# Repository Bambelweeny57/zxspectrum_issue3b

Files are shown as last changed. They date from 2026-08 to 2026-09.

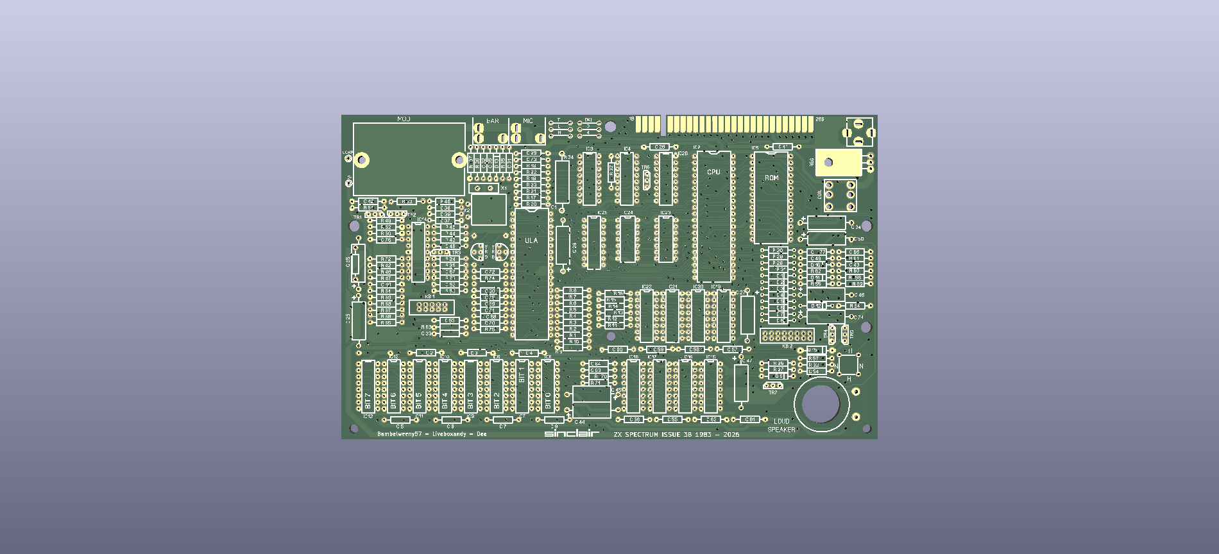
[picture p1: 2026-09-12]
images/unpopulated - issue3b.png

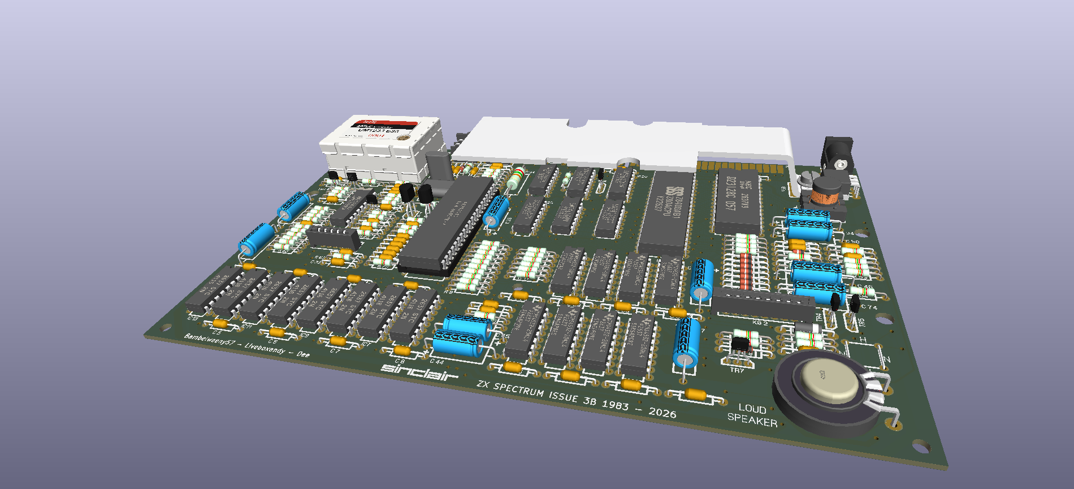
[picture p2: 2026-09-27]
images/issue3b.png

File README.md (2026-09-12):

# **ZX Spectrum Issue 3B — KiCad Reconstruction**

A faithful KiCad recreation of the **Sinclair ZX Spectrum Issue 3B motherboard**, reconstructed from original Gerber data and fully validated through multiple successful builds.  
This project preserves the 3B layout in an editable, open format and includes several companion PCBs designed to modernise, repair, or enhance the original Spectrum hardware.

---

## 🧭 Project Purpose

The aim of this repository is to provide a clean, accurate, and reproducible version of the Issue 3B board for:

- Restoring original machines  
- Building new units from scratch  
- Hardware experimentation and modding  
- Long‑term preservation of Sinclair’s design  

All PCBs included here have been **physically manufactured and tested**.

---

## 🛠️ Included PCBs

### **✔️ Issue 3B Motherboard (KiCad Reconstruction)**  
A complete KiCad recreation of the original Issue 3B board.

- Rebuilt directly from Gerbers  
- Trace‑accurate routing  
- Multiple boards assembled and working perfectly  
- Compatible with original components and modern equivalents  

---

### **✔️ Coil Replacement PCB**  
A compact, reliable drop‑in replacement for the original Spectrum coil assembly.

- Tested and working  
- More consistent output than ageing originals  
- Builder‑friendly footprint and assembly  

---

### **✔️ Composite Mod PCB (Internal Modulator Replacement)**  
This PCB is designed to **fit inside the original RF modulator can**, replacing the internal circuitry while keeping the metal can for authenticity.

- Produces a clean composite video output  
- Eliminates RF noise and modulator‑related issues  
- Fully validated on real hardware  
- Ideal for restorations where the external appearance should remain original  

---

### **✔️ Composite Modulator Replacement PCB**  
A full PCB replacement for the RF modulator can itself.

- Suitable for new builds or heavily damaged modulators  
- Provides modern composite output in a clean, serviceable form  
- Tested and working  

---

## 🧩 Issue 3B Schematic

A full schematic for the **Issue 3B motherboard** is now complete.  
It lives in the main **`/src`** directory alongside the KiCad PCB project and is useful for reference, verification, and troubleshooting.

- Based on the reconstructed PCB  
- Continuously refined as traces and nets are validated  
- Intended to become a complete, accurate representation of the 3B circuitry  
- A PDF export is also included in **`/documents`** for quick viewing

---

## 📁 Repository Structure

| Path | Description |
|---|---|
| `/bom` | Interactive Bill of Materials |
| `/case` | £D models and images of a alternatice case |
| `/documents` | Schematics etc. |
| `/gerber` | Fabrication files |
| `/images` | Images of the PCB's |
| `/keyboard` | Mechanical Keyswitch Keyboard to fit the Case |
| `/src` | KiCad project files for the Issue 3B board |
| `/zx_coil` | Coil replacement PCB |
| `/zx_composite_mod` | Composite mod PCB (internal modulator replacement) |
| `/zx_composite_modulator` | Full modulator replacement PCB |
| `README.md` | Project overview |

---

## 🔧 Build Status

All PCBs in this repository have been **successfully manufactured, assembled, and tested**.

| PCB | Status |
|-----|---|
| Issue 3B Motherboard | ✅ Working |
| Coil Replacement PCB | ✅ Working |
| Composite Mod PCB | ✅ Working |
| Composite Modulator PCB | ✅ Working |

---

## 📐 About the Issue 3B Revision

The Issue 3B is one of the later 48K Spectrum board revisions, featuring:

- Improved manufacturing consistency  
- Minor routing and grounding refinements  
- Updated power regulation layout  
- Compatibility with both early and late ULAs  

This reconstruction preserves the original routing and component placement as closely as possible.

---

## 🤝 Contributing

Contributions that improve accuracy, documentation, or long‑term preservation of the Issue 3B are welcome.  
This includes:

- Verified corrections to the schematic or PCB reconstruction  
- High‑resolution board scans, trace photos, or component placement references  
- Improvements to KiCad symbols, footprints, or net annotations  
- Build reports, troubleshooting notes, or compatibility findings  
- Additional companion PCBs that relate to the 3B ecosystem  

Please open an issue or pull request with clear details so changes can be reviewed and validated against real hardware where possible.

---

## 🤝 Credits

Based on the redraw by PABB - https://www.pcbway.com/project/shareproject/ZX_Spectrum_48_Issue_3B_Redrawn.html

Special thanks to Liveboxandy for reconstructing the base footprints for the iBOM and 3D Models view and Dee for the Coil, Keyboard and Audio Connectors, Modulator, Speaker, ULA, CPU, ROM and Heat Sink 3D Models.

---

## 📜 License

This project is released for educational, preservation, and hobbyist use.  
You are free to study, modify, and build from the files provided.

The original Sinclair ZX Spectrum design remains the intellectual property of its respective rights holders.  
Please respect the historical significance of the original hardware.

---

## 🚀 How to Use This Project

### **Open in KiCad**
```bash
git clone https://github.com/Bambelweeny57/zxspectrum_issue3b

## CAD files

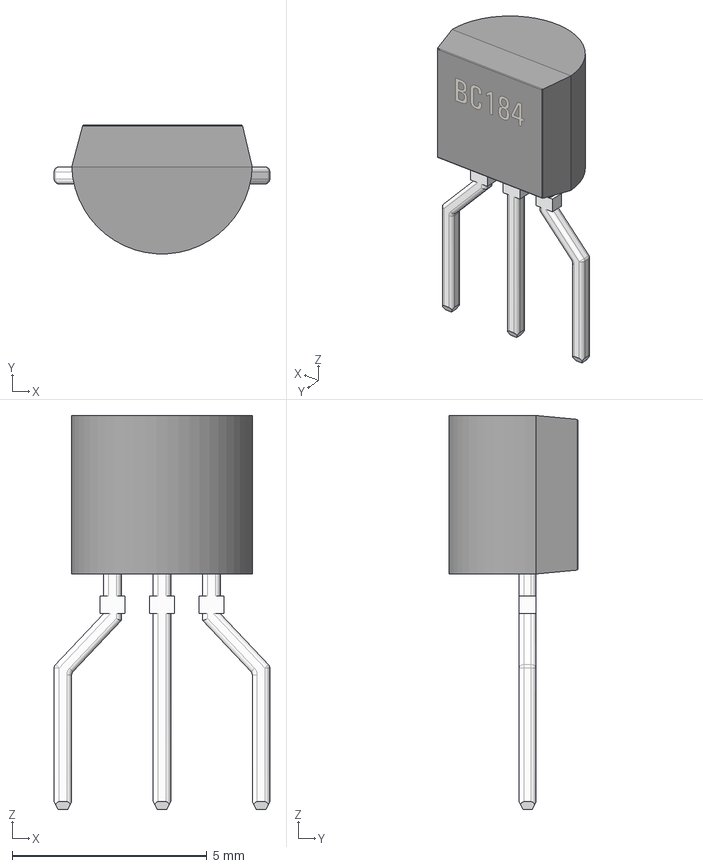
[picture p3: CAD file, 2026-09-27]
src/STPS/BC184.step
5.53 x 3.30 x 10.1 mm
Legs
TO92

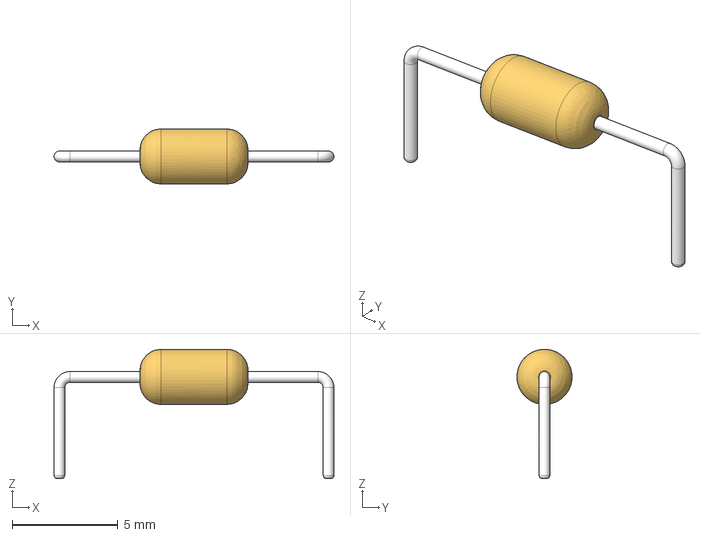
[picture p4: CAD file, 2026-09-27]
src/STPS/CAP_AXIAL_THT_L5.1-D3.1-P12.70.step
13.2 x 2.60 x 6.10 mm

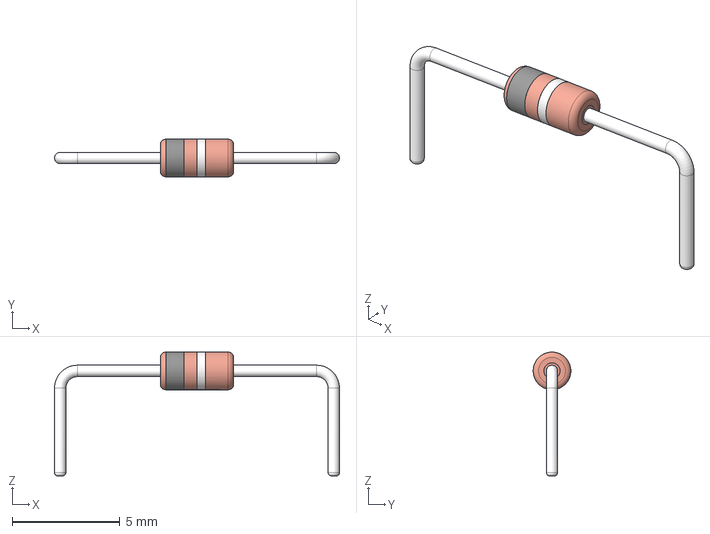
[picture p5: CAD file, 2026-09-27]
src/STPS/DO-35_P12.70-D0.53.step
13.2 x 1.75 x 5.75 mm

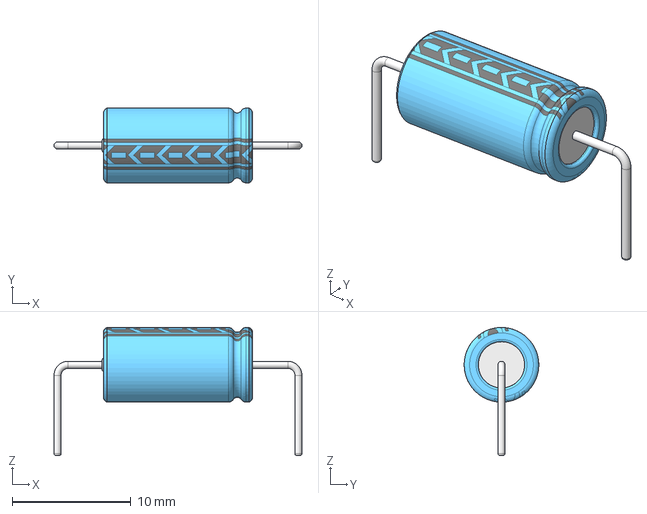
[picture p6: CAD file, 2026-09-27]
src/STPS/CAP-TH_BD6.3-L12.0-P20.32-D0.6.step
20.9 x 6.30 x 10.8 mm

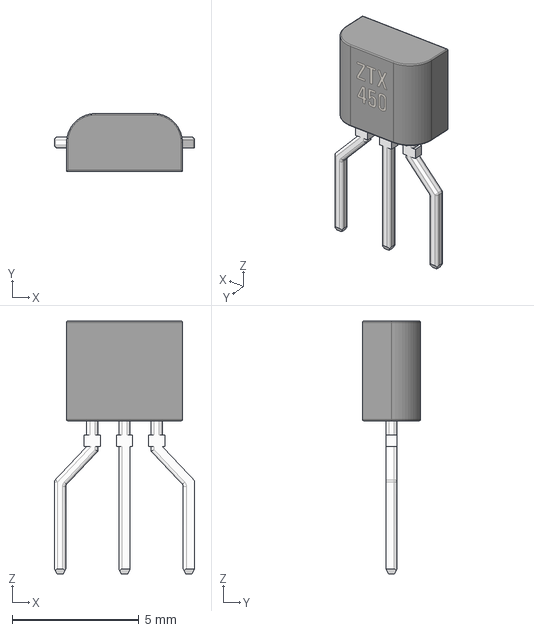
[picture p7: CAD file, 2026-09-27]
src/STPS/ZTX_450.step
5.53 x 2.29 x 9.98 mm
Legs
ELINE

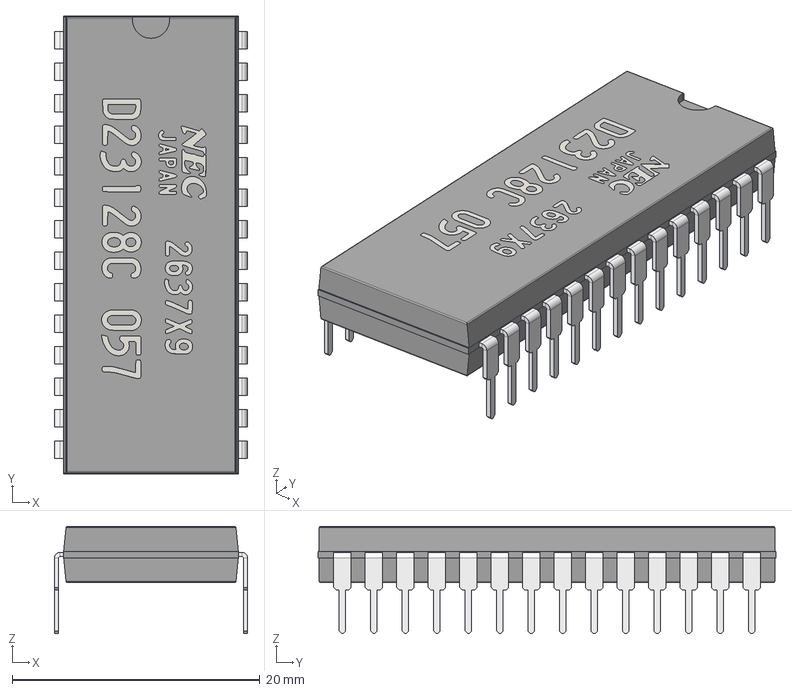
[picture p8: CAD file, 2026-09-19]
src/STPS/ROM NEC D2318C.step
15.6 x 37.0 x 8.64 mm
Basic - DIP40 Wide v2
DIP Pin v2
DIP Pin v2(Mirror)

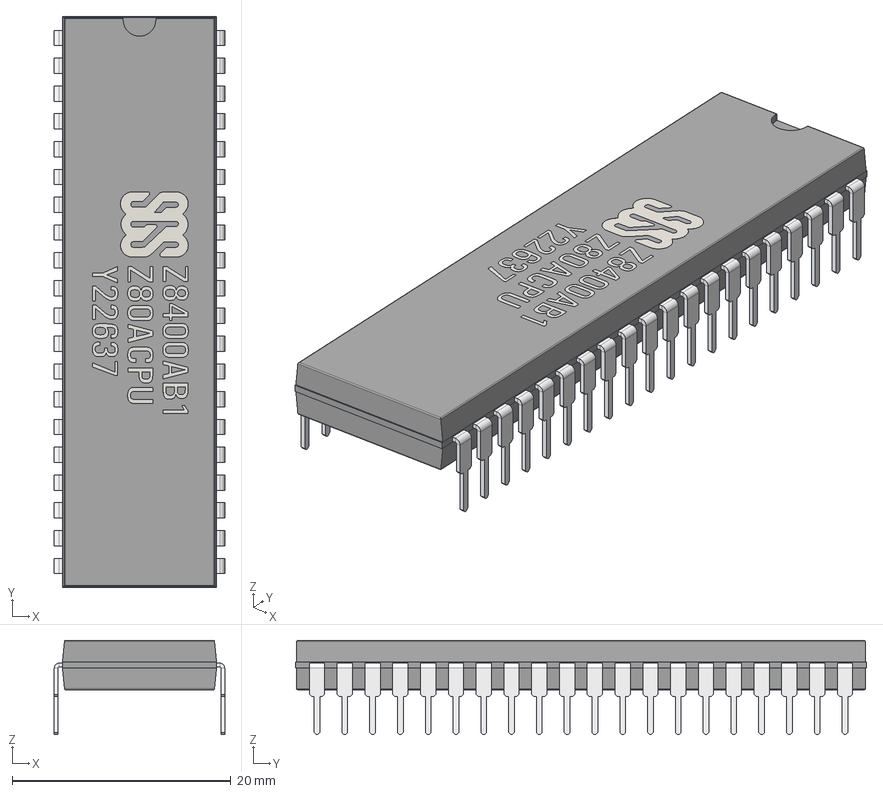
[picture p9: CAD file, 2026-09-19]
src/STPS/Z80 - SGS.step
15.6 x 52.2 x 8.64 mm
Basic - DIP40 Wide v2
DIP Pin v2
DIP Pin v2(Mirror)

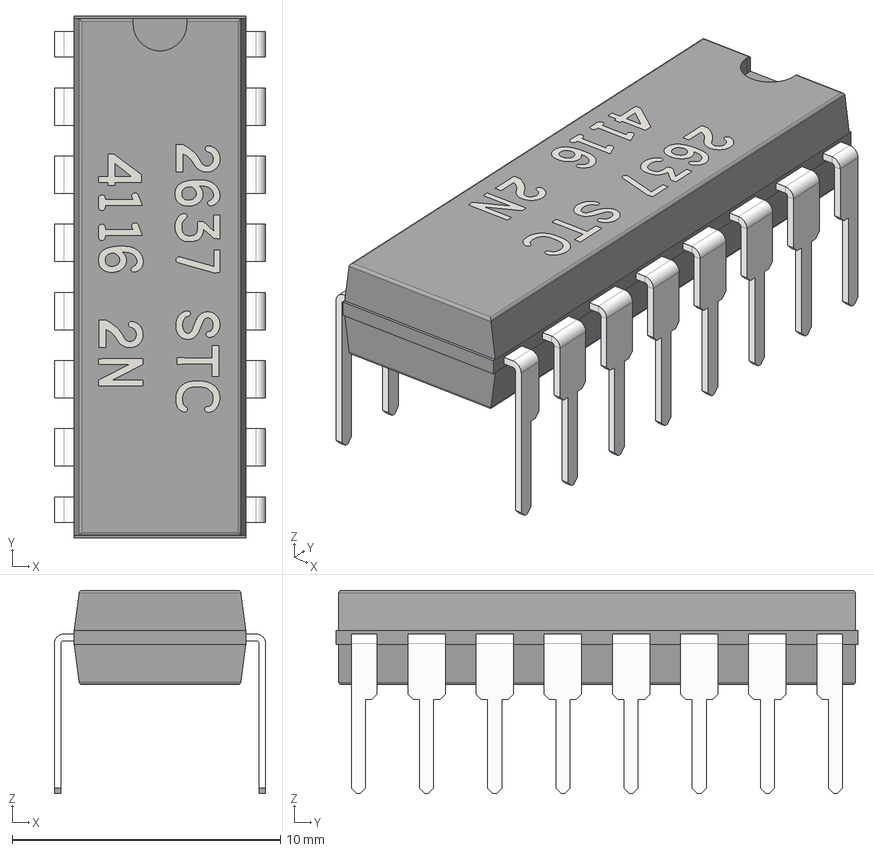
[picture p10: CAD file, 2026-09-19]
src/STPS/STC_4116.step
7.87 x 19.5 x 7.57 mm
Basic - DIP 7.62 v3
DIP Pin 14-20 v3
DIP Pin 14-20 v3(Mirror)

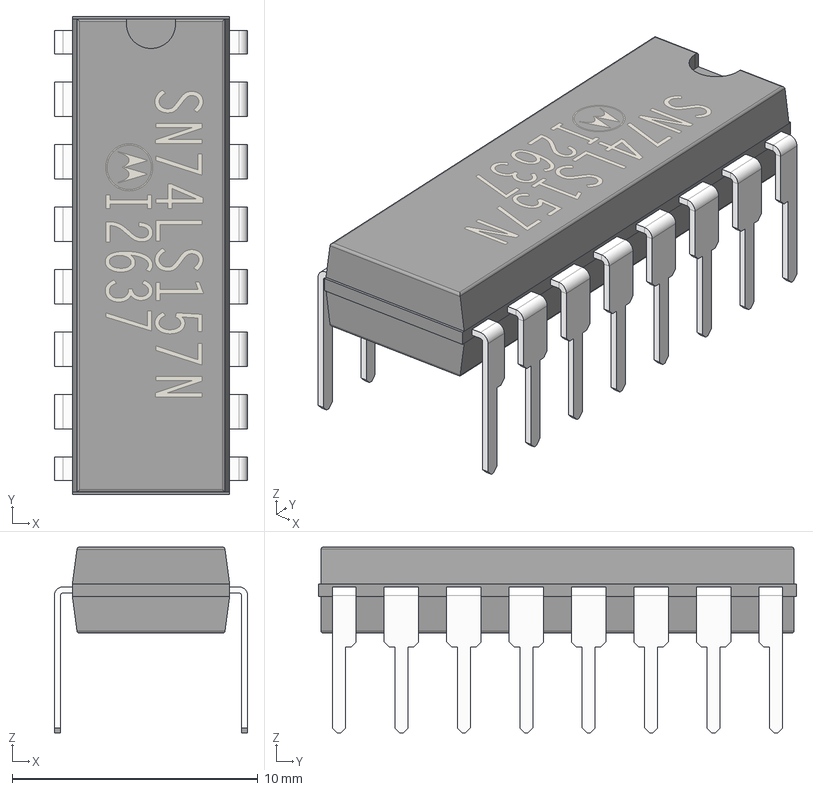
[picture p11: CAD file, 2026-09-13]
src/STPS/MOT_SN74LS157N.step
7.87 x 19.5 x 7.57 mm
Basic - DIP 7.62 v3
DIP Pin 14-20 v3
DIP Pin 14-20 v3(Mirror)

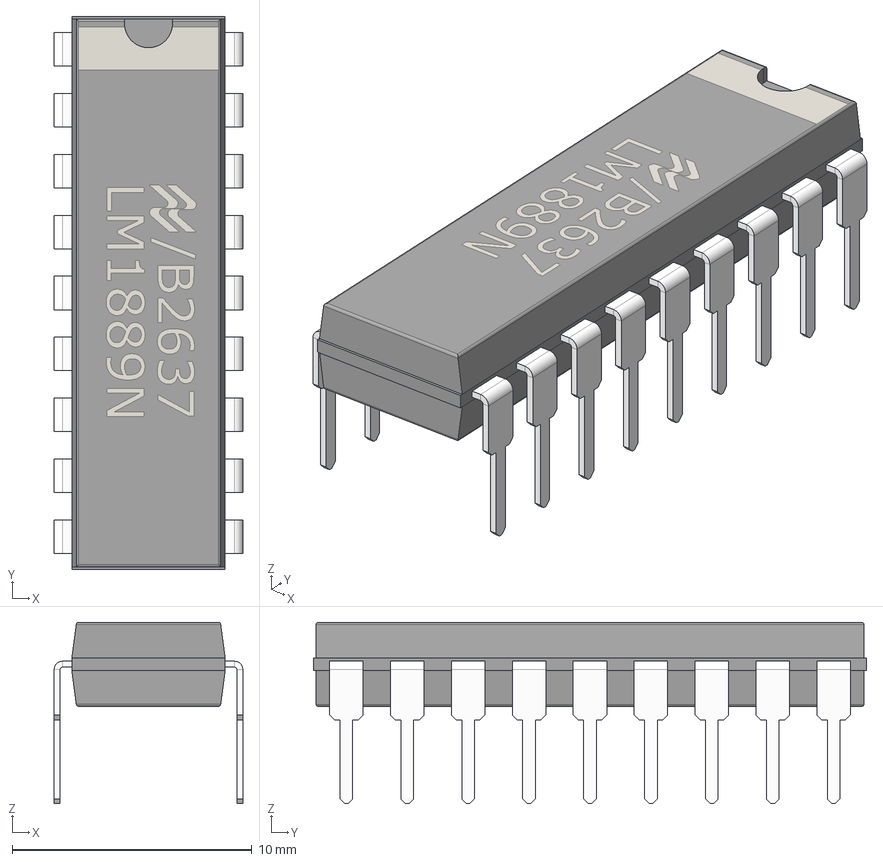
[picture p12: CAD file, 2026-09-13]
src/STPS/NS_LM1889N.step
7.87 x 23.1 x 7.57 mm
Basic - DIP 7.62 v3
DIP Pin 14-20 v3
DIP Pin 14-20 v3(Mirror)

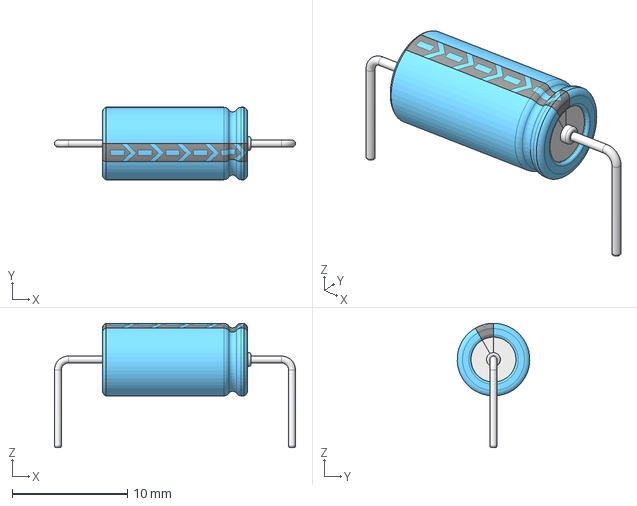
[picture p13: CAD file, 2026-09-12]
src/STPS/Axial Capacitor.step
20.9 x 6.29 x 10.8 mm

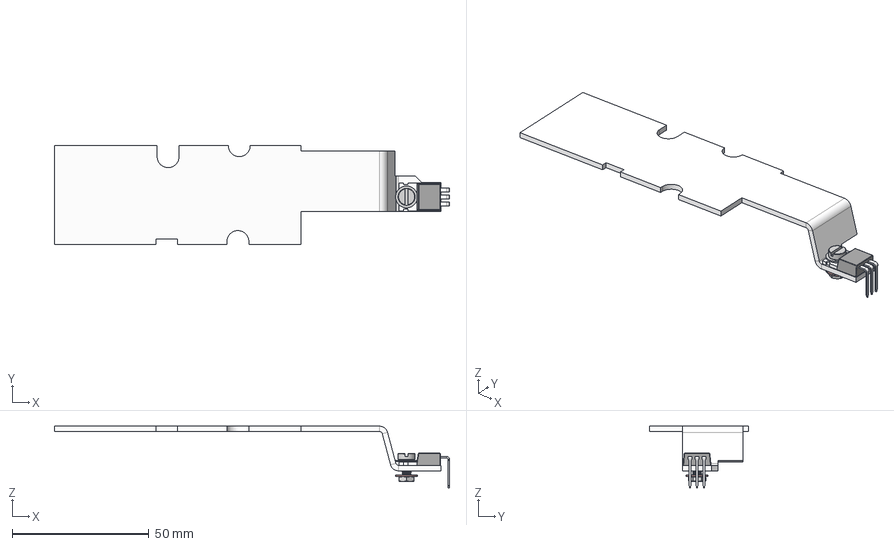
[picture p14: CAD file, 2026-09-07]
src/STPS/LM7805 with Heatsink i3.step
144.3 x 36.0 x 22.5 mm
Heatsink
TO-220-3
Screw
93925A250_Internal Tooth Lock Washers
90695A033_Medium-Strength Steel Thin-Profile Hex Nut
Fibre Washer

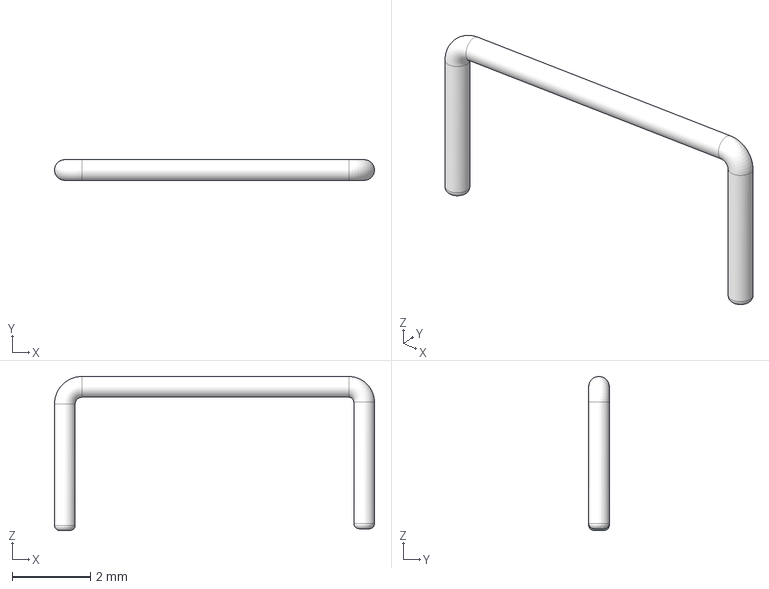
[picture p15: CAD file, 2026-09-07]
src/STPS/Jumper.step
8.18 x 0.53 x 3.94 mm

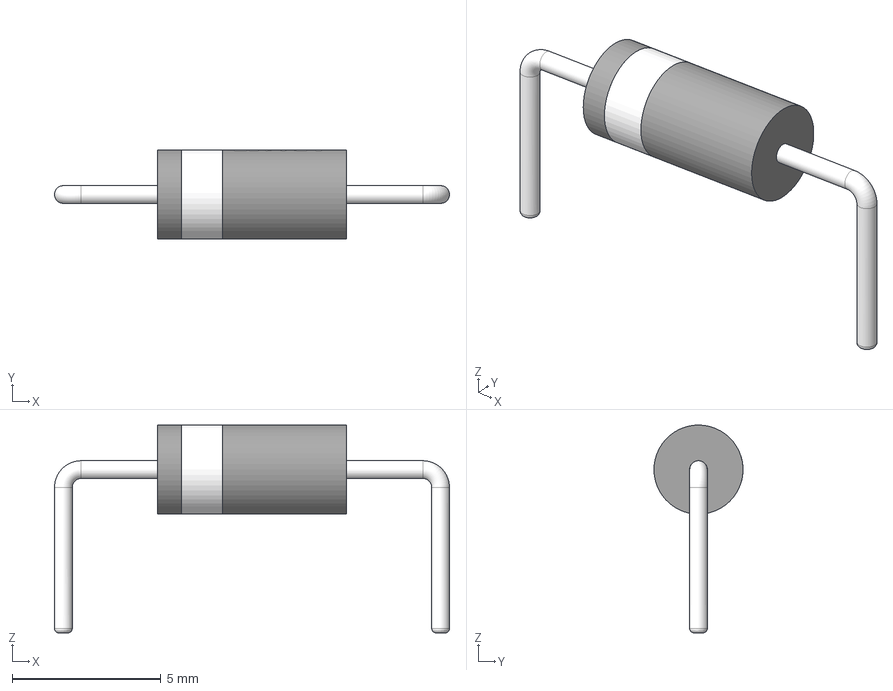
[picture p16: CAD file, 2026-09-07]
src/STPS/DO-35_P12.70_BA157.step
13.3 x 3.00 x 7.00 mm
Wire
Diode Body

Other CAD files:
src/STPS/MOT_SN74532N.step
src/STPS/MOT_SN74LS00N.step
src/STPS/ITT_4116.step
src/STPS/TI_TMS4532.step
src/STPS/13.34x13.34 Bobin.STEP
src/STPS/22-02-3053.stp
src/STPS/22-02-3083.stp
src/STPS/AUDIO_JACK_3PIN.step
src/STPS/COIL_L1.step
src/STPS/CONN-TH_5P-P2.54_520315-5.step
src/STPS/CONN-TH_8P-P2.54_520315-8.step
src/STPS/CP 13x5x0.5x20.32.STEP
src/STPS/Capacitor Ceramic No Polarity axial 12.70.STEP
src/STPS/Crystal-HC18-U RA.STEP
src/STPS/Crystal-Low.stp
src/STPS/DC Power Connector FC68148_20DC10A_202.1mm.STP
src/STPS/DIP-14_W7.62mm.step
src/STPS/DIP-14_W7.62mm_Socket.step
src/STPS/DIP-16_W7.62mm.step
src/STPS/DIP-16_W7.62mm_Socket.step
src/STPS/DIP-18_W7.62mm.step
src/STPS/DIP-18_W7.62mm_Socket.step
src/STPS/DIP-24_W10.16mm.step
src/STPS/DIP-24_W10.16mm_Socket.step
src/STPS/DIP-28_W15.24mm.step
src/STPS/DIP-28_W15.24mm_Socket.step
src/STPS/DIP-40_W15.24mm.step
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

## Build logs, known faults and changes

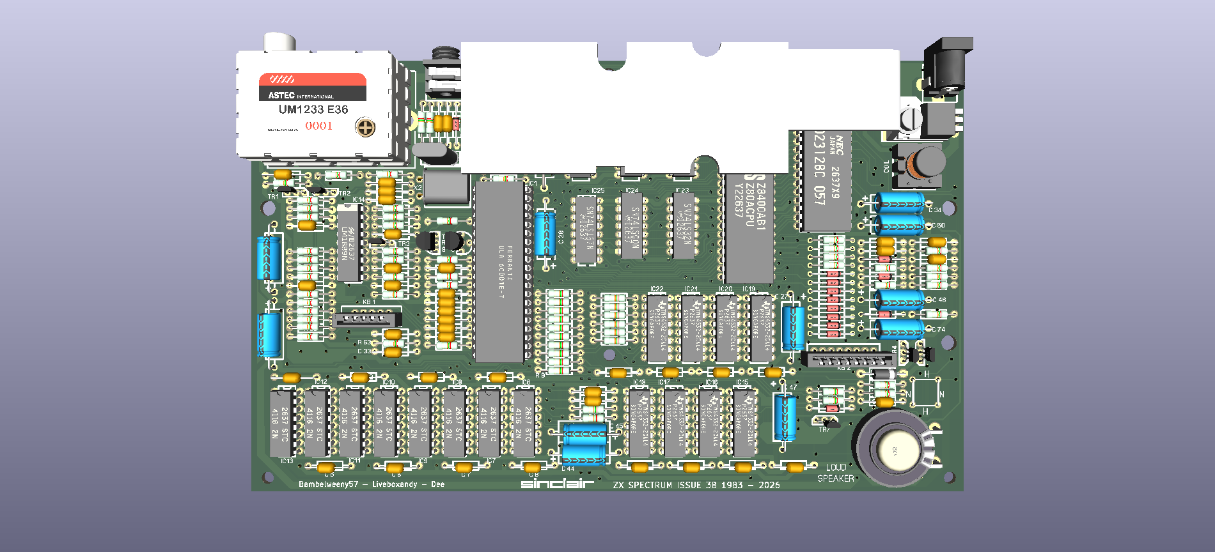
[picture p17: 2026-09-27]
images/populated - issue3b.png

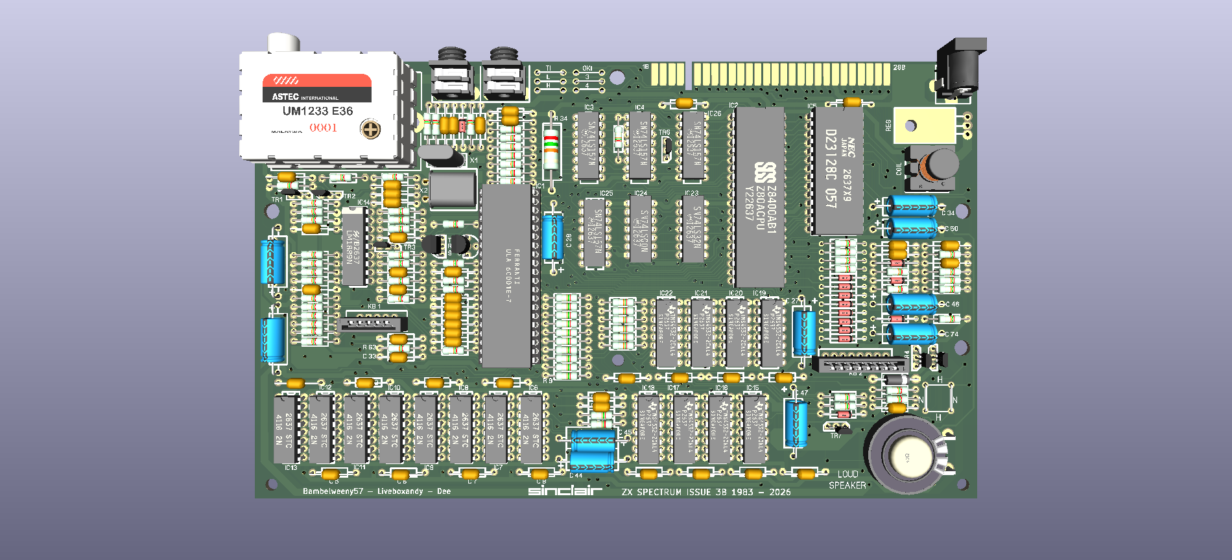
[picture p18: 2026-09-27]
images/populated - no heatsink - issue3b.png

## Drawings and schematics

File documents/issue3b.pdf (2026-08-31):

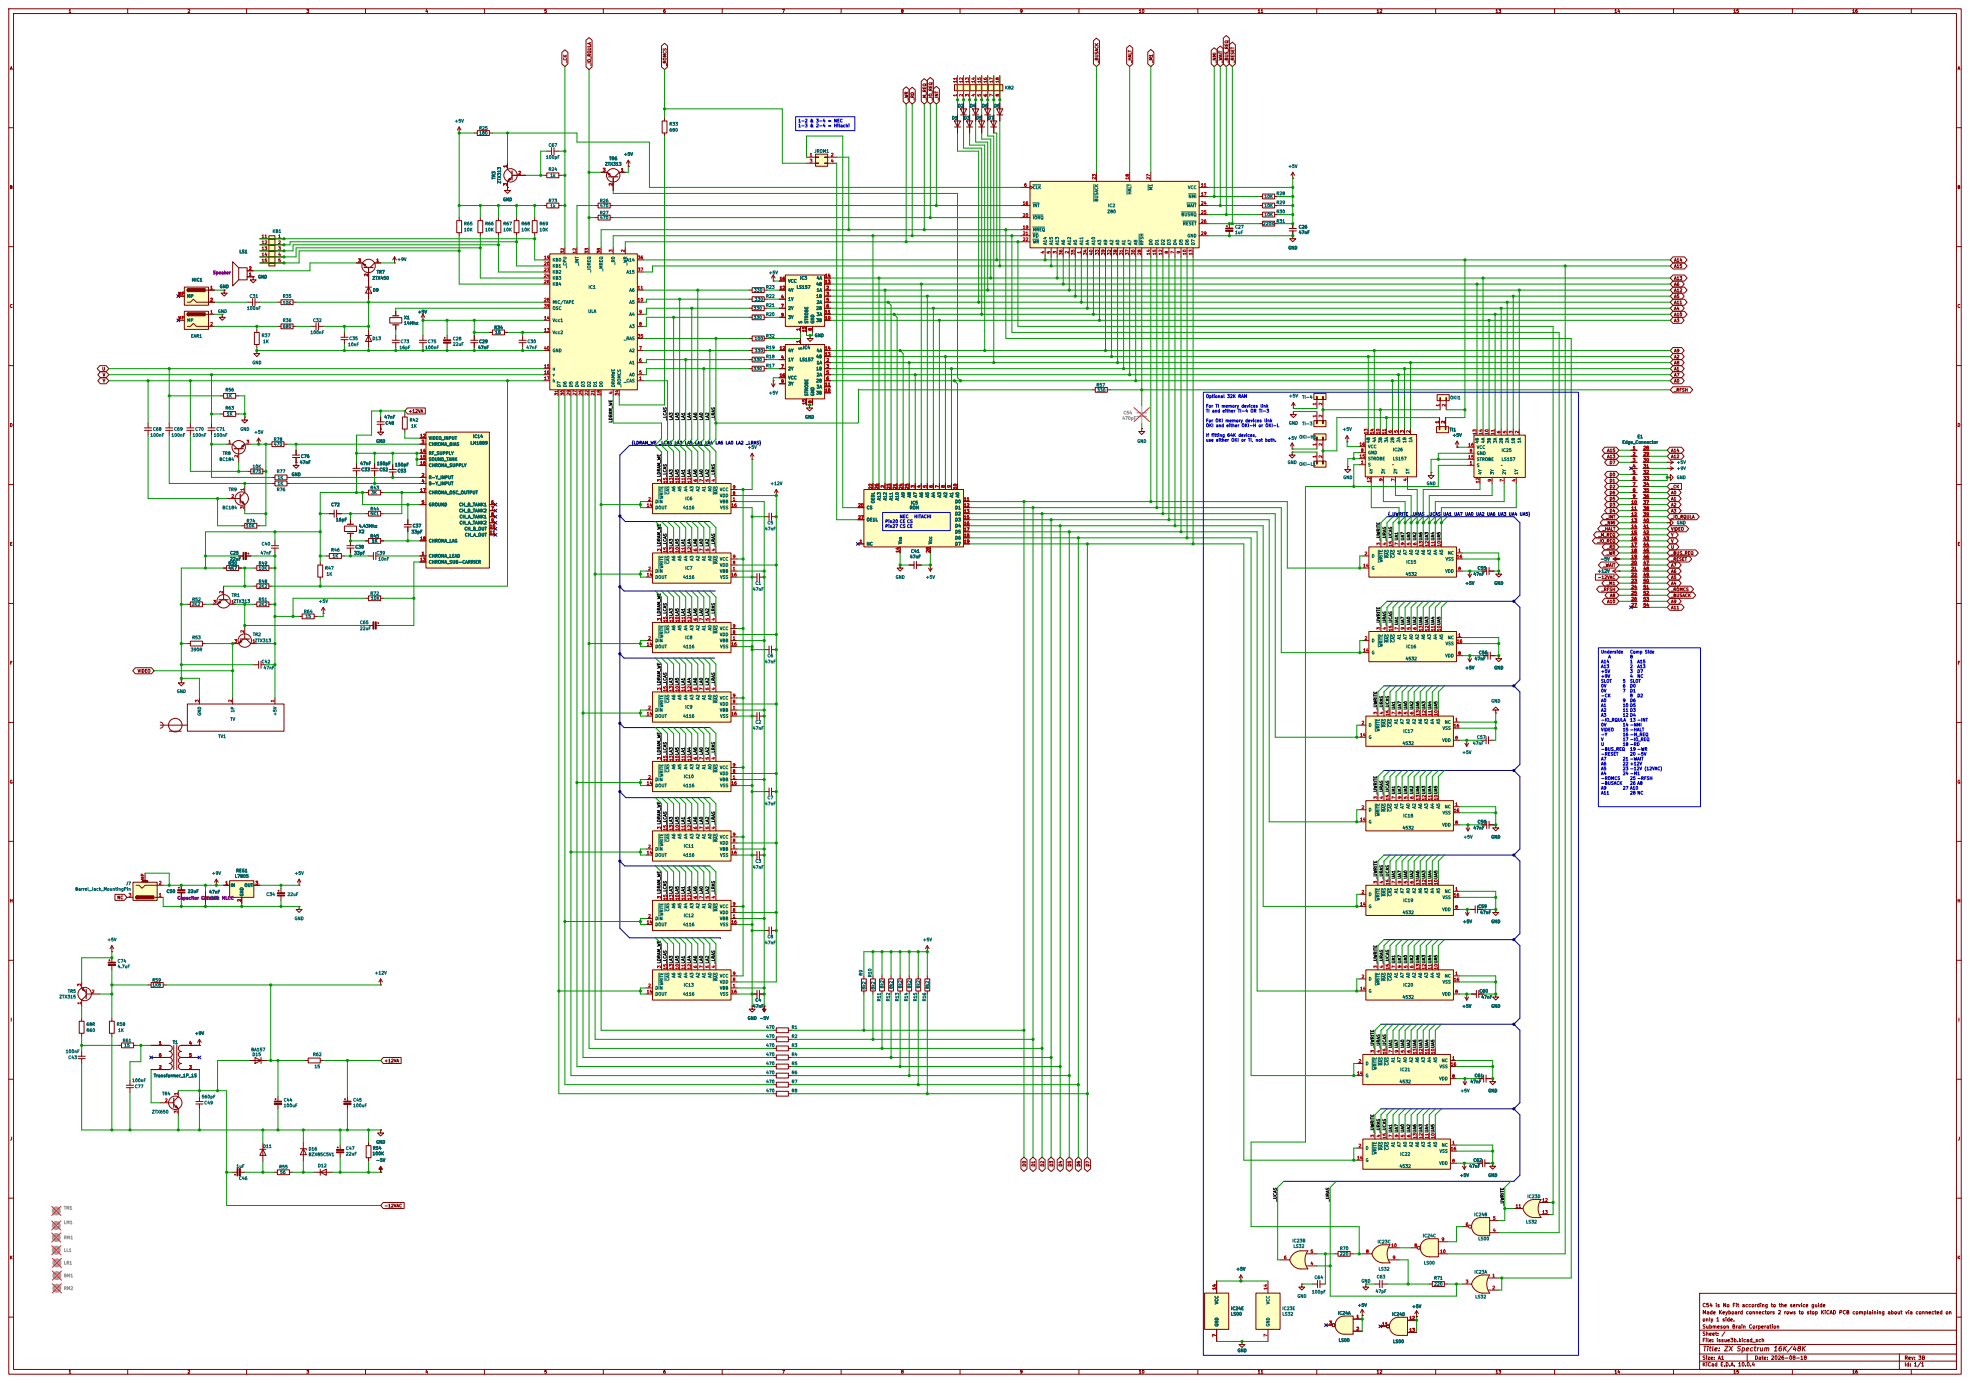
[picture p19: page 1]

For TI memory devices link
TI and either TI-4 OR TI-3

For OKI memory devices link OKI and either OKI-H or OKI-L

IC5 ROM
NEC HITACHI Pin20 CE CS Pin27 CS CE

VDD | 8 A7

VDD 4532 | 8 A7

Made Keyboard connectors 2 rows to stop KiCAD PCB complaining about via connected on C54 is No Fit according to the service guide

Size: A1 | Rev: 3B
KiCad E.D.A. 10.0.4 | Id: 1/1

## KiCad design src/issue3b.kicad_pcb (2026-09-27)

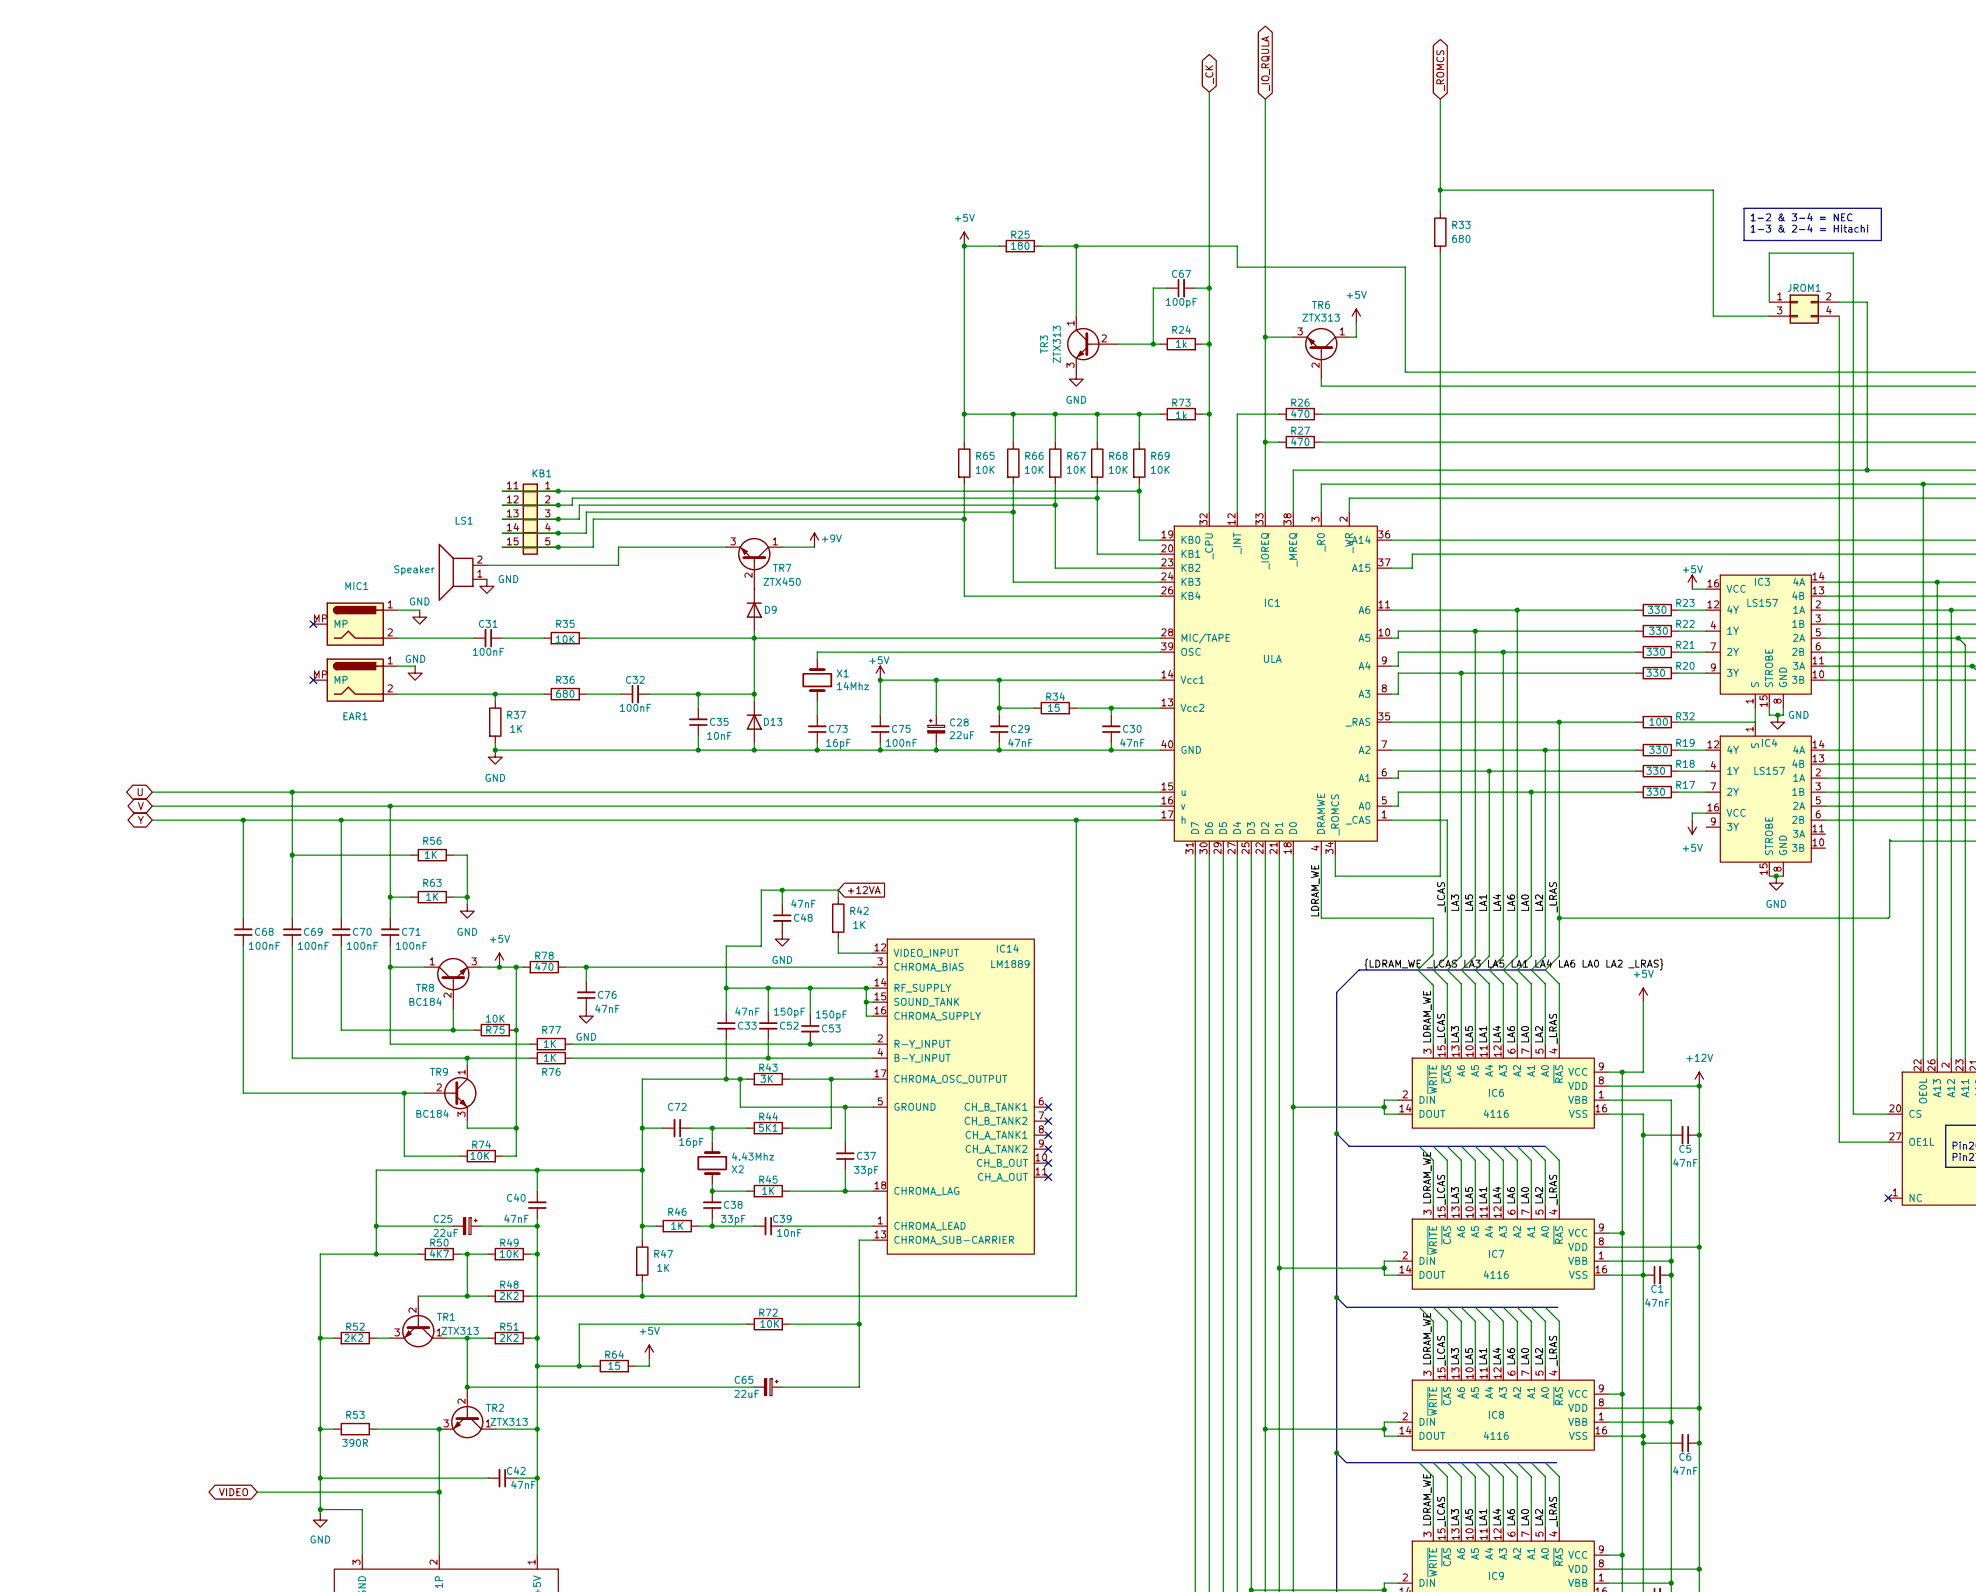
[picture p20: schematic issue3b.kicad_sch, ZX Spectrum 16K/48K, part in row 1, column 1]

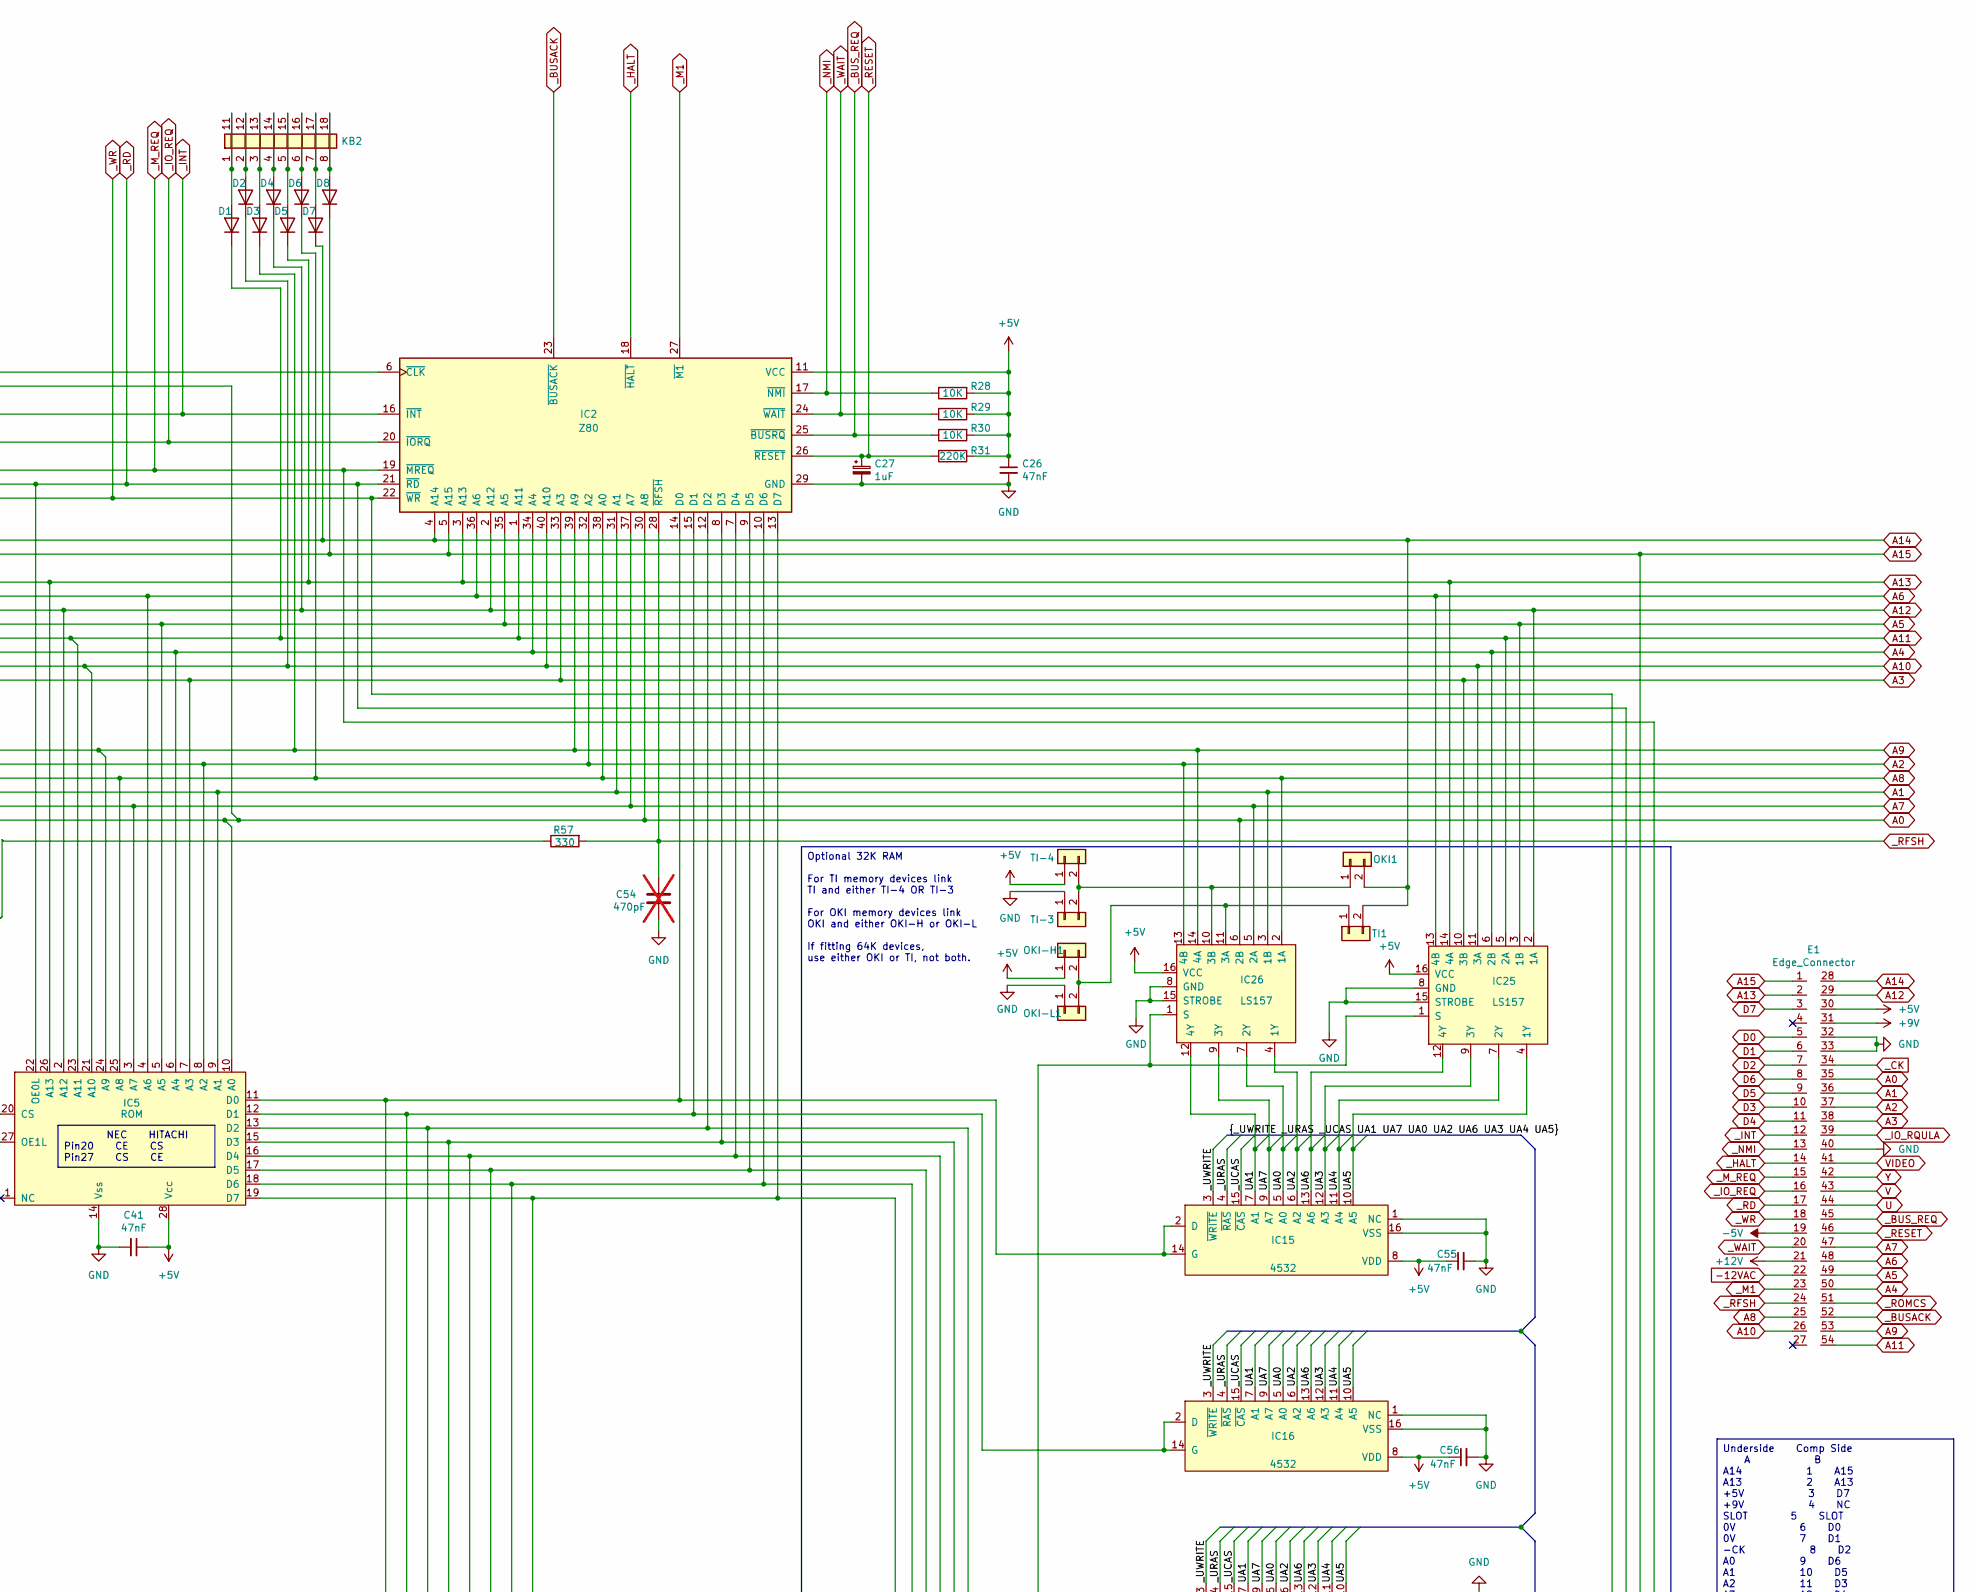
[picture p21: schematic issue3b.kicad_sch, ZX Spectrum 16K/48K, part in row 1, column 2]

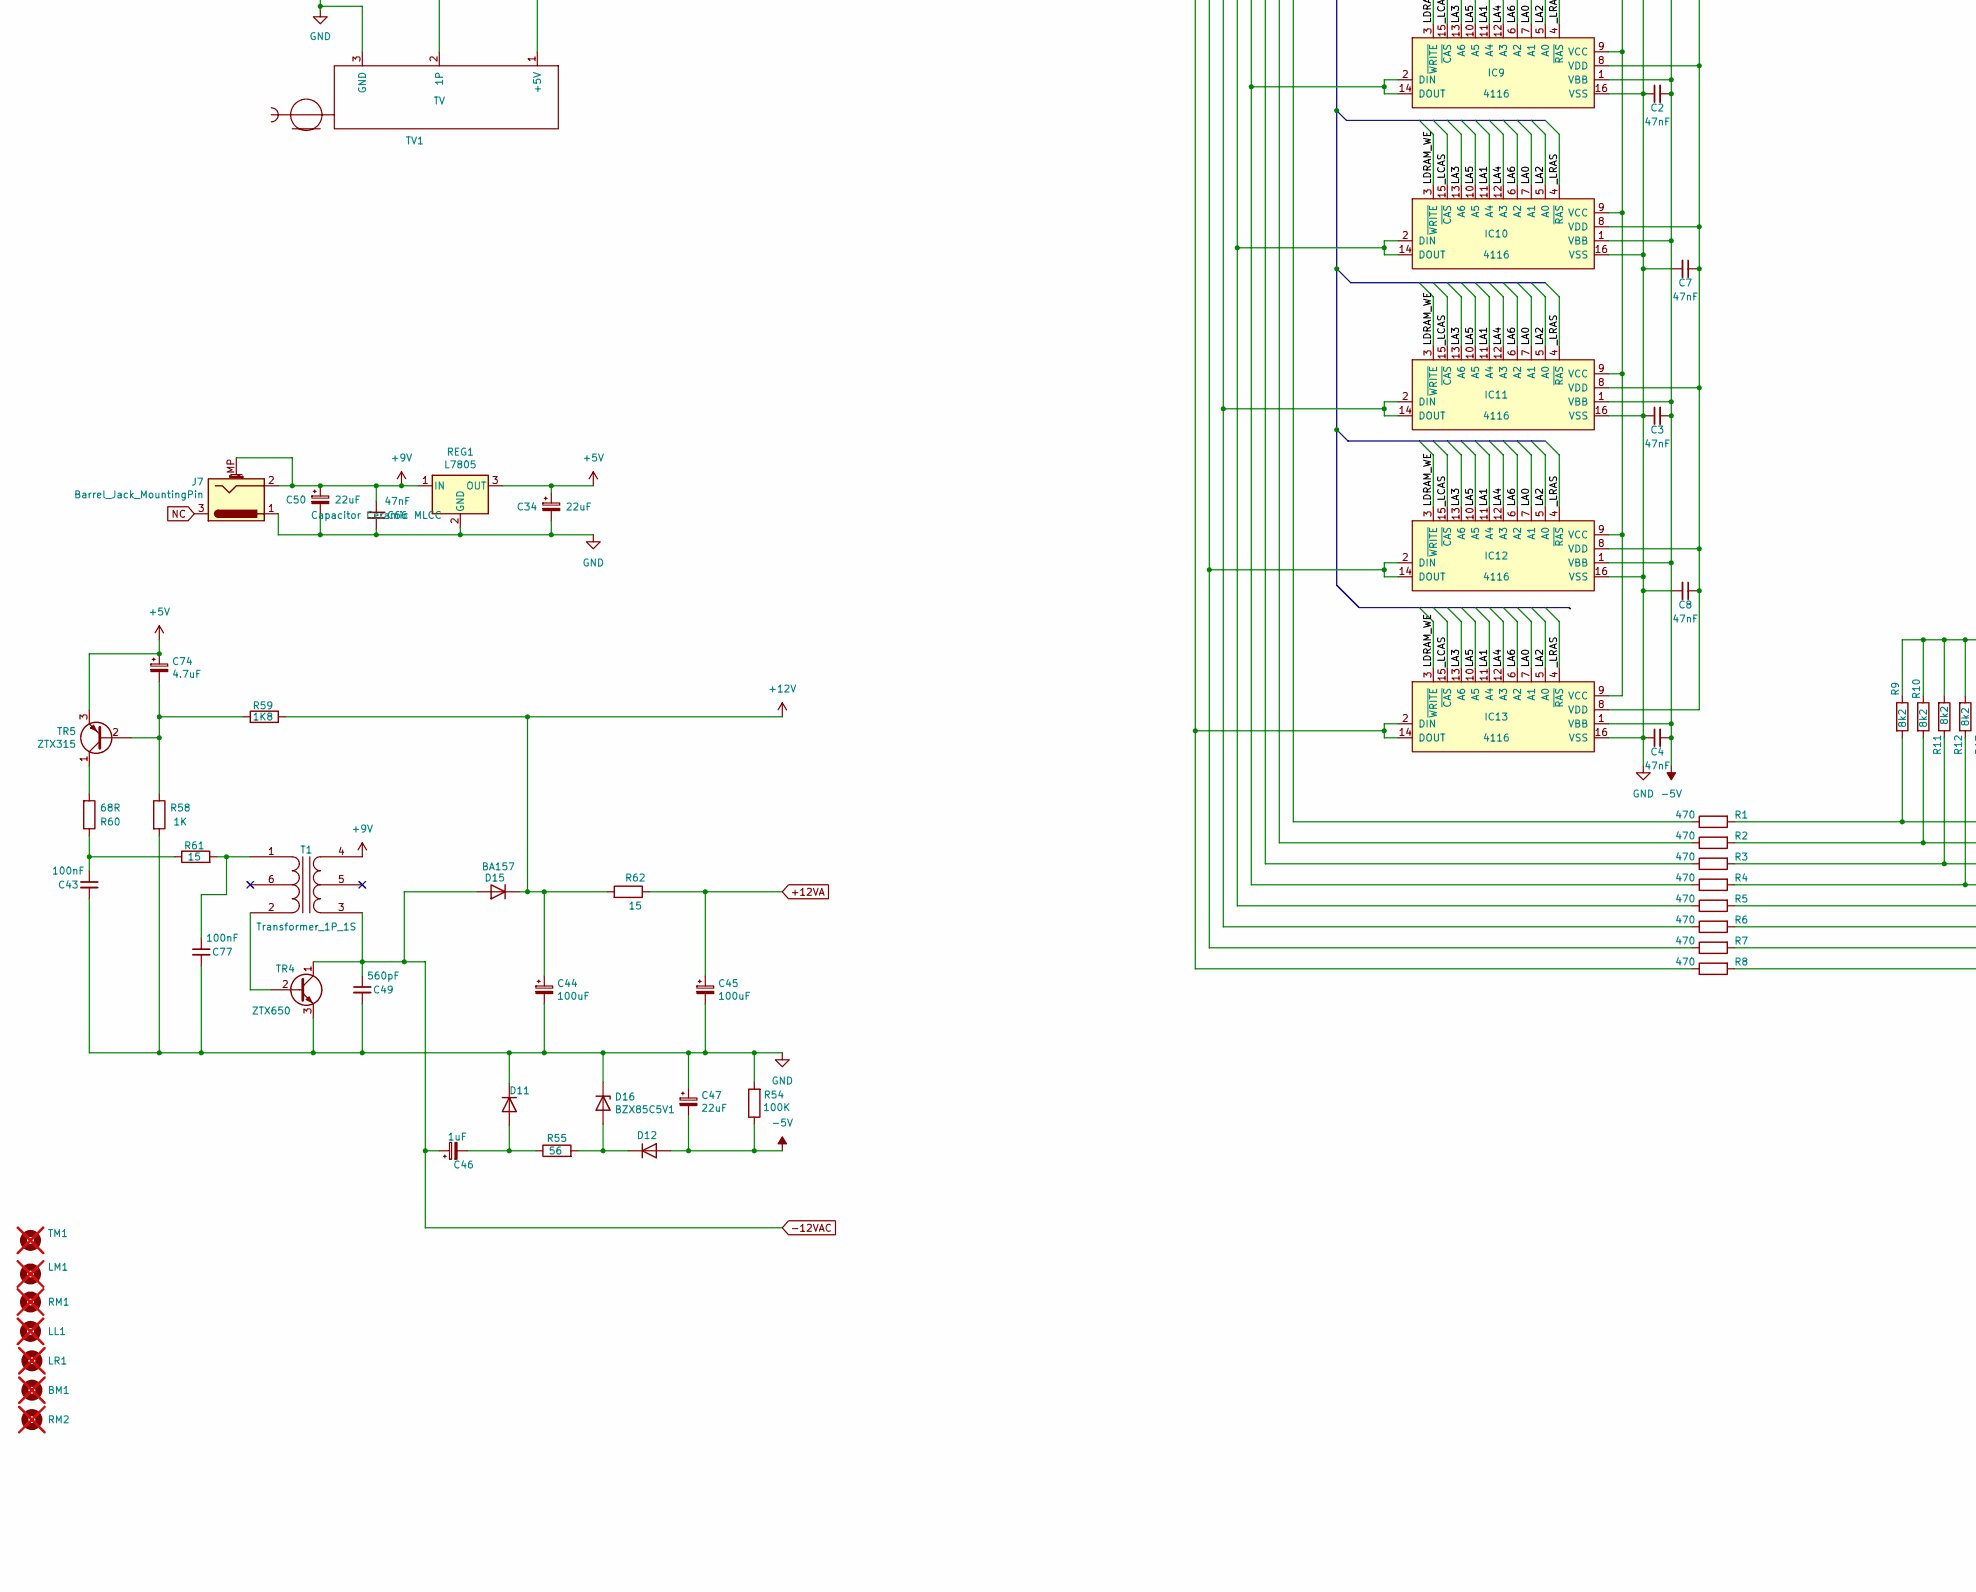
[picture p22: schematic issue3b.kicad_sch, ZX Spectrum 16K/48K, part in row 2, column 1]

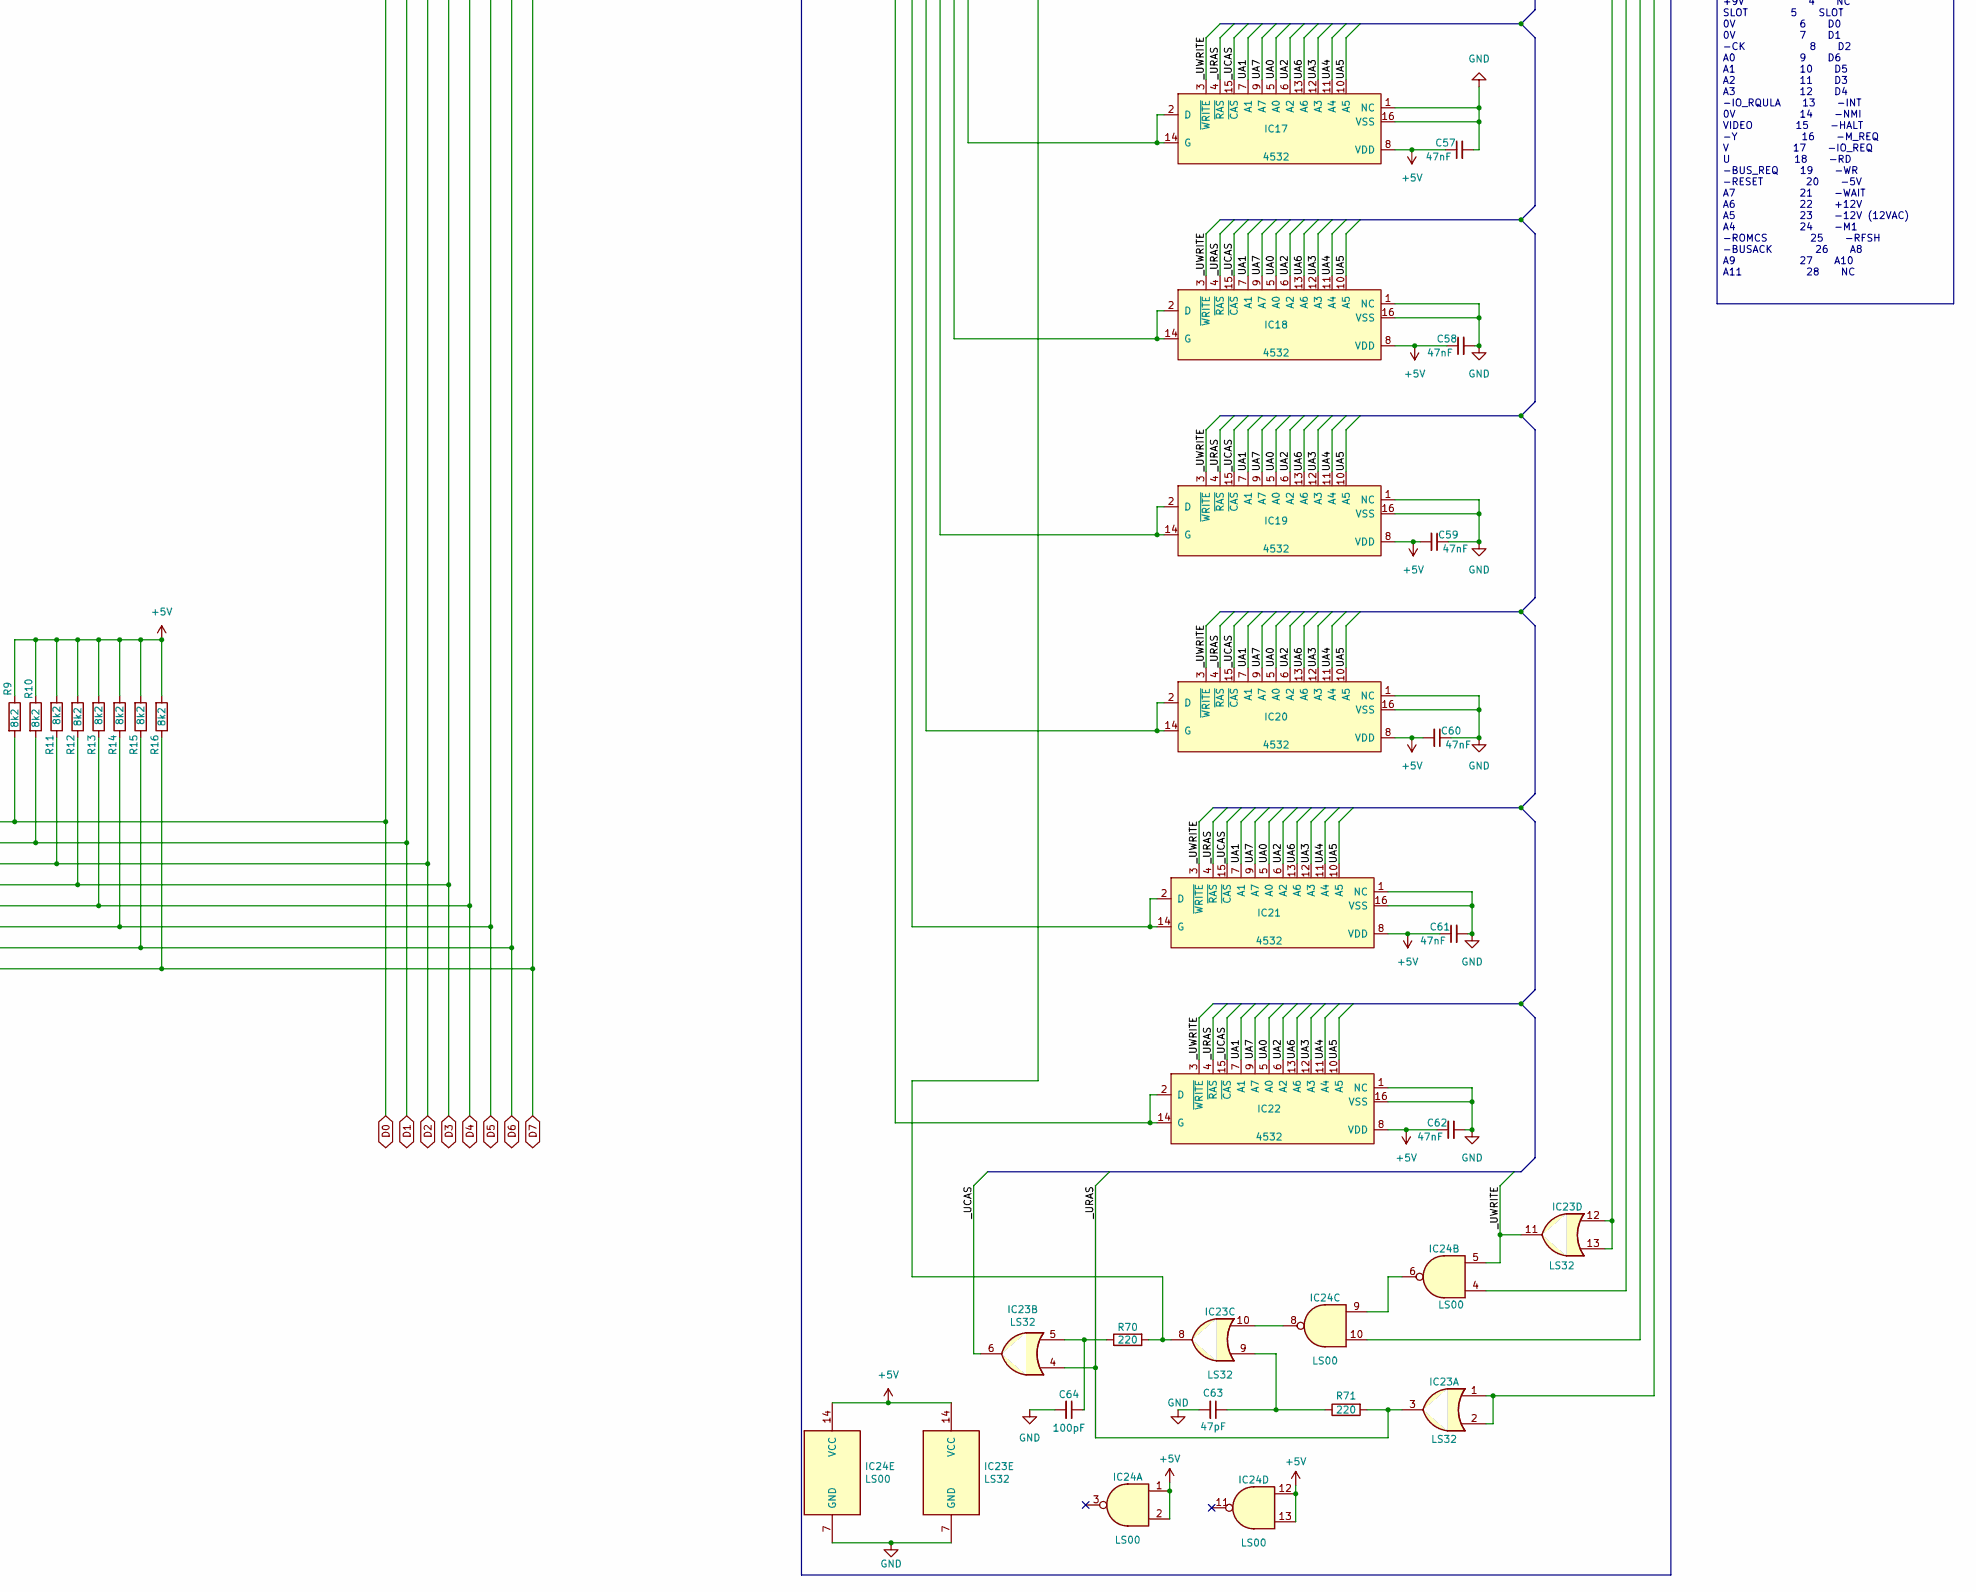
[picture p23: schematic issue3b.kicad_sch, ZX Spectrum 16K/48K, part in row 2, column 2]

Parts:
BM1: MountingHole; MountingHole_3.3mm Spectrum; not fitted
C1, C2, C3, C4, C5, C6, C7, C8, C26, C29, C30, C33, C40, C41, C42, C48, C55, C56, C57, C58, C59, C60, C61, C62, C66, C76: 47nF; C_Axial_L3.8mm_D2.6mm_P12.70mm_Horizontal
C25: 22uF; CP_Axial_L11.0mm_D6.0mm_P20.00mm_Horizontal
C27: 1uF; CP_Axial_L11.0mm_D6.0mm_P20.00mm_Horizontal
C28, C34, C47, C50, C65: 22uF; CP_Axial_L11.0mm_D6.0mm_P20.32mm_Horizontal
C31, C32: 100nF; C_Axial_L3.8mm_D2.6mm_P12.40mm_Horizontal
C35: 10nF; C_Axial_L3.8mm_D2.6mm_P12.40mm_Horizontal
C37, C38: 33pF; C_Axial_L3.8mm_D2.6mm_P12.70mm_Horizontal
C39: 10nF; C_Axial_L3.8mm_D2.6mm_P12.70mm_Horizontal
C43, C68, C69, C70, C71, C75, C77: 100nF; C_Axial_L3.8mm_D2.6mm_P12.70mm_Horizontal
C44, C45: 100uF; CP_Axial_L11.0mm_D6.0mm_P20.32mm_Horizontal
C46: 1uF; CP_Axial_L11.0mm_D6.0mm_P20.32mm_Horizontal
C49: 560pF; C_Axial_L3.8mm_D2.6mm_P12.70mm_Horizontal
C52, C53: 150pF; C_Axial_L3.8mm_D2.6mm_P12.70mm_Horizontal
C54: 470pF; C_Axial_L3.8mm_D2.6mm_P12.70mm_Horizontal; not fitted
C63: 47pF; C_Axial_L3.8mm_D2.6mm_P12.70mm_Horizontal
C64, C67: 100pF; C_Axial_L3.8mm_D2.6mm_P12.70mm_Horizontal
C72, C73: 16pF; C_Axial_L3.8mm_D2.6mm_P12.70mm_Horizontal
C74: 4.7uF; CP_Axial_L11.0mm_D6.0mm_P20.32mm_Horizontal
D1, D2, D3, D4, D5, D6, D7, D8, D9, D11, D12: 1N4148; D_DO-35_SOD27_P12.70mm_Horizontal
D13: 1N4148; D_DO-35_SOD27_P12.40mm_Horizontal
D15: BA157; D_DO-35_SOD27_P12.70mm_Horizontal
D16: BZX85C5V1; D_DO-35_SOD27_P12.70mm_Horizontal
E1: Edge_Connector; Edge Connector
EAR1: EAR1; 3.5mm_socket
IC1: ULA; DIP-40_W15.24mm_Socket
IC2: Z80; DIP-40_W15.24mm_Socket
IC3, IC4, IC25, IC26: LS157; DIP-16_W7.62mm_Socket
IC5: ROM; DIP-28_W15.24mm_Socket
IC6, IC7, IC8, IC9, IC10, IC11, IC12, IC13: 4116; DIP-16_W7.62mm_Socket
IC14: LM1889; DIP-18_W7.62mm_Socket
IC15, IC16, IC17, IC18, IC19, IC20, IC21, IC22: 4532; DIP-16_W7.62mm_Socket
IC23: LS32; DIP-14_W7.62mm_Socket
IC24: LS00; DIP-14_W7.62mm_Socket
J7: Barrel_Jack_MountingPin; BarrelJack_Horizontal
JROM1: JROM; ROM_WireLink
KB1: Keyboard5
KB2: Keyboard8
LL1: MountingHole; MountingHole_3.3mm Spectrum; not fitted
LM1: MountingHole; MountingHole_5mm Spectrum; not fitted
LR1: MountingHole; MountingHole_3.3mm Spectrum; not fitted
LS1: Speaker
MIC1: MIC1; 3.5mm_socket
OKI1: OKI; Wire_Link_7.62mm
OKI-H1: OKI-H; Wire_Link_7.62mm
OKI-L1: OKI-L; Wire_Link_7.62mm
R1, R2, R3, R4, R5, R6, R7, R8, R26, R27, R78: 470; R_Yageo_L3.6mm_D1.6mm_P12.70mm_Horizontal
R9, R10, R11, R12, R13, R14, R15, R16: 8k2; R_Yageo_L3.6mm_D1.6mm_P12.70mm_Horizontal
R17, R18, R19, R20, R21, R22, R23, R57: 330; R_Yageo_L3.6mm_D1.6mm_P12.70mm_Horizontal
R24, R73: 1k; R_Yageo_L3.6mm_D1.6mm_P12.70mm_Horizontal
R25: 180; R_Yageo_L3.6mm_D1.6mm_P12.70mm_Horizontal
R28, R29, R30, R49, R65, R66, R67, R68, R69, R72, R74, R75: 10K; R_Yageo_L3.6mm_D1.6mm_P12.70mm_Horizontal
R31: 220K; R_Yageo_L3.6mm_D1.6mm_P12.70mm_Horizontal
R32: 100; R_Yageo_L3.6mm_D1.6mm_P12.70mm_Horizontal
R33: 680; R_Yageo_L3.6mm_D1.6mm_P12.70mm_Horizontal
R34: 15; R_Axial_DIN0516_L15.5mm_D5.0mm_P22.60mm_Horizontal
R35: 10K; R_Yageo_L3.6mm_D1.6mm_P12.40mm_Horizontal
R36: 680; R_Yageo_L3.6mm_D1.6mm_P12.40mm_Horizontal
R37: 1K; R_Yageo_L3.6mm_D1.6mm_P12.40mm_Horizontal
R42, R45, R46, R47, R56, R58, R63, R76, R77: 1K; R_Yageo_L3.6mm_D1.6mm_P12.70mm_Horizontal
R43: 3K; R_Yageo_L3.6mm_D1.6mm_P12.70mm_Horizontal
R44: 5K1; R_Yageo_L3.6mm_D1.6mm_P12.70mm_Horizontal
R48, R51, R52: 2K2; R_Yageo_L3.6mm_D1.6mm_P12.70mm_Horizontal
R50: 4K7; R_Yageo_L3.6mm_D1.6mm_P12.70mm_Horizontal
R53: 390R; R_Yageo_L3.6mm_D1.6mm_P12.70mm_Horizontal
R54: 100K; R_Yageo_L3.6mm_D1.6mm_P12.70mm_Horizontal
R55: 56; R_Yageo_L3.6mm_D1.6mm_P12.70mm_Horizontal
R59: 1K8; R_Yageo_L3.6mm_D1.6mm_P12.70mm_Horizontal
R60: 68R; R_Yageo_L3.6mm_D1.6mm_P12.70mm_Horizontal
R61, R62, R64: 15; R_Yageo_L3.6mm_D1.6mm_P12.70mm_Horizontal
R70, R71: 220; R_Yageo_L3.6mm_D1.6mm_P12.70mm_Horizontal
REG1: L7805; TO-220-3_Horizontal_TabDown
RM1, RM2: MountingHole; MountingHole_5mm Spectrum; not fitted
T1: Transformer_1P_1S; Coil
TI1: TI; Wire_Link_7.62mm
TI-3: TI-3; Wire_Link_7.62mm
TI-4: TI-4; Wire_Link_7.62mm
TM1: MountingHole; MountingHole_3.3mm Spectrum; not fitted
TR1, TR2, TR3, TR6: ZTX313; TO-92Flat
TR4: ZTX650; TO-92Flat
TR5: ZTX315; TO-92Flat
TR7: ZTX450; TO-92Flat
TR8, TR9: BC184; TR9
TV1: TV; Modulator
X1: 14Mhz; X1
X2: 4.43Mhz; X2

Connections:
+5V: C26.1, C28.1, C29.2, C34.1, C41.1, C55.1, C56.1, C57.1, C58.1, C59.2, C60.2, C61.1, C62.1, C74.1, C75.2, E1.30, IC1.14 (Vcc1), IC2.11 (VCC), IC3.16 (VCC), IC4.16 (VCC), IC5.28 (Vcc), IC6.9 (VCC), IC7.9 (VCC), IC8.9 (VCC), IC9.9 (VCC), IC10.9 (VCC), IC11.9 (VCC), IC12.9 (VCC), IC13.9 (VCC), IC15.8 (VDD), IC16.8 (VDD), IC17.8 (VDD), IC18.8 (VDD), IC19.8 (VDD), IC20.8 (VDD), IC21.8 (VDD), IC22.8 (VDD), IC23.14 (VCC), IC24.1, IC24.2, IC24.12, IC24.13, IC24.14 (VCC), IC25.16 (VCC), IC26.16 (VCC), OKI-H1.1, R9.1, R10.1, R11.2, R12.2, R13.2, R14.2, R15.2, R16.2, R25.2, R28.2, R29.2, R30.2, R31.1, R34.1, R64.2, R65.1, R66.1, R67.1, R68.1, R69.1, R73.2, R74.2, R75.2, R78.2, REG1.3 (OUT), TI-4.1, TR5.3 (E), TR6.1 (C), TR8.3 (E), TR9.3 (E)
+9V: C50.1, C66.1, E1.31, J7.2, J7.MP (MountPin), REG1.1 (IN), T1.4 (SB), TR7.1 (C)
+12V: C5.1, C6.1, C7.1, C8.1, C44.1, D15.1 (K), E1.21, IC6.8 (VDD), IC7.8 (VDD), IC8.8 (VDD), IC9.8 (VDD), IC10.8 (VDD), IC11.8 (VDD), IC12.8 (VDD), IC13.8 (VDD), R59.2, R62.2
+12VA: C33.1, C45.1, C48.1, C52.1, C53.1, IC14.14 (RF_SUPPLY), IC14.15 (SOUND_TANK), IC14.16 (CHROMA_SUPPLY), R42.1, R62.1
-5V: C1.2, C2.2, C3.2, C4.2, C47.2, D12.2 (A), E1.19, IC6.1 (VBB), IC7.1 (VBB), IC8.1 (VBB), IC9.1 (VBB), IC10.1 (VBB), IC11.1 (VBB), IC12.1 (VBB), IC13.1 (VBB), R54.1
-12VAC: C46.1, C49.1, D15.2 (A), E1.22, T1.3 (SA), TR4.1 (C)
/LA0: IC1.5 (A0), IC6.7 (A1), IC7.7 (A1), IC8.7 (A1), IC9.7 (A1), IC10.7 (A1), IC11.7 (A1), IC12.7 (A1), IC13.7 (A1), R17.1
/LA1: IC1.6 (A1), IC6.11 (A4), IC7.11 (A4), IC8.11 (A4), IC9.11 (A4), IC10.11 (A4), IC11.11 (A4), IC12.11 (A4), IC13.11 (A4), R18.1
/LA2: IC1.7 (A2), IC6.5 (A0), IC7.5 (A0), IC8.5 (A0), IC9.5 (A0), IC10.5 (A0), IC11.5 (A0), IC12.5 (A0), IC13.5 (A0), R19.1
/LA3: IC1.8 (A3), IC6.13 (A6), IC7.13 (A6), IC8.13 (A6), IC9.13 (A6), IC10.13 (A6), IC11.13 (A6), IC12.13 (A6), IC13.13 (A6), R20.1
/LA4: IC1.9 (A4), IC6.12 (A3), IC7.12 (A3), IC8.12 (A3), IC9.12 (A3), IC10.12 (A3), IC11.12 (A3), IC12.12 (A3), IC13.12 (A3), R21.1
/LA5: IC1.10 (A5), IC6.10 (A5), IC7.10 (A5), IC8.10 (A5), IC9.10 (A5), IC10.10 (A5), IC11.10 (A5), IC12.10 (A5), IC13.10 (A5), R22.1
/LA6: IC1.11 (A6), IC6.6 (A2), IC7.6 (A2), IC8.6 (A2), IC9.6 (A2), IC10.6 (A2), IC11.6 (A2), IC12.6 (A2), IC13.6 (A2), R23.1
/LDRAM_WE: IC1.4 (DRAMWE), IC6.3 (~WRITE), IC7.3 (~WRITE), IC8.3 (~WRITE), IC9.3 (~WRITE), IC10.3 (~WRITE), IC11.3 (~WRITE), IC12.3 (~WRITE), IC13.3 (~WRITE)
/UA0: IC15.5 (A0), IC16.5 (A0), IC17.5 (A0), IC18.5 (A0), IC19.5 (A0), IC20.5 (A0), IC21.5 (A0), IC22.5 (A0), IC26.7 (2Y)
/UA1: IC15.7 (A1), IC16.7 (A1), IC17.7 (A1), IC18.7 (A1), IC19.7 (A1), IC20.7 (A1), IC21.7 (A1), IC22.7 (A1), IC26.12 (4Y)
/UA2: IC15.6 (A2), IC16.6 (A2), IC17.6 (A2), IC18.6 (A2), IC19.6 (A2), IC20.6 (A2), IC21.6 (A2), IC22.6 (A2), IC26.4 (1Y)
/UA3: IC15.12 (A3), IC16.12 (A3), IC17.12 (A3), IC18.12 (A3), IC19.12 (A3), IC20.12 (A3), IC21.12 (A3), IC22.12 (A3), IC25.9 (3Y)
/UA4: IC15.11 (A4), IC16.11 (A4), IC17.11 (A4), IC18.11 (A4), IC19.11 (A4), IC20.11 (A4), IC21.11 (A4), IC22.11 (A4), IC25.7 (2Y)
/UA5: IC15.10 (A5), IC16.10 (A5), IC17.10 (A5), IC18.10 (A5), IC19.10 (A5), IC20.10 (A5), IC21.10 (A5), IC22.10 (A5), IC25.4 (1Y)
/UA6: IC15.13 (A6), IC16.13 (A6), IC17.13 (A6), IC18.13 (A6), IC19.13 (A6), IC20.13 (A6), IC21.13 (A6), IC22.13 (A6), IC25.12 (4Y)
/UA7: IC15.9 (A7), IC16.9 (A7), IC17.9 (A7), IC18.9 (A7), IC19.9 (A7), IC20.9 (A7), IC21.9 (A7), IC22.9 (A7), IC26.9 (3Y)
/_LCAS: IC1.1 (_CAS), IC6.15 (~CAS), IC7.15 (~CAS), IC8.15 (~CAS), IC9.15 (~CAS), IC10.15 (~CAS), IC11.15 (~CAS), IC12.15 (~CAS), IC13.15 (~CAS)
/_LRAS: IC1.35 (_RAS), IC6.4 (~RAS), IC7.4 (~RAS), IC8.4 (~RAS), IC9.4 (~RAS), IC10.4 (~RAS), IC11.4 (~RAS), IC12.4 (~RAS), IC13.4 (~RAS), R32.2, R57.1
/_UCAS: IC15.15 (~CAS), IC16.15 (~CAS), IC17.15 (~CAS), IC18.15 (~CAS), IC19.15 (~CAS), IC20.15 (~CAS), IC21.15 (~CAS), IC22.15 (~CAS), IC23.6
/_URAS: IC15.4 (~RAS), IC16.4 (~RAS), IC17.4 (~RAS), IC18.4 (~RAS), IC19.4 (~RAS), IC20.4 (~RAS), IC21.4 (~RAS), IC22.4 (~RAS), IC23.3, IC23.4, R71.2
/_UWRITE: IC15.3 (~WRITE), IC16.3 (~WRITE), IC17.3 (~WRITE), IC18.3 (~WRITE), IC19.3 (~WRITE), IC20.3 (~WRITE), IC21.3 (~WRITE), IC22.3 (~WRITE), IC23.11, IC24.5
A0: E1.35, IC2.30 (A8), IC4.6 (2B), IC5.10 (A0), IC26.6 (2B), TR6.2 (B)
A1: E1.36, IC2.31 (A1), IC4.3 (1B), IC5.9 (A1), IC26.3 (1B)
A2: E1.37, IC2.32 (A2), IC4.13 (4B), IC5.8 (A2), IC26.13 (4B)
A3: E1.38, IC2.33 (A3), IC3.10 (3B), IC5.7 (A3), IC25.10 (3B)
A4: E1.50, IC2.34 (A4), IC3.6 (2B), IC5.6 (A4), IC25.6 (2B)
A5: E1.49, IC2.35 (A5), IC3.3 (1B), IC5.5 (A5), IC25.3 (1B)
A6: E1.48, IC2.36 (A6), IC3.13 (4B), IC5.4 (A6), IC25.13 (4B)
A7: E1.47, IC2.37 (A7), IC4.5 (2A), IC5.3 (A7), IC26.5 (2A)
A8: D6.1 (K), E1.25, IC2.38 (A0), IC4.2 (1A), IC5.25 (A8), IC26.2 (1A)
A9: D3.1 (K), E1.53, IC2.39 (A9), IC4.14 (4A), IC5.24 (A9), IC26.14 (4A)
A10: D2.1 (K), E1.26, IC2.40 (A10), IC3.11 (3A), IC5.21 (A10), IC25.11 (3A)
A11: D1.1 (K), E1.54, IC2.1 (A11), IC3.5 (2A), IC5.23 (A11), IC25.5 (2A)
A12: D4.1 (K), E1.29, IC2.2 (A12), IC3.2 (1A), IC5.2 (A12), IC25.2 (1A)
A13: D5.1 (K), E1.2, IC2.3 (A13), IC3.14 (4A), IC5.26 (A13), IC25.14 (4A)
A14: D7.1 (K), E1.28, IC1.36 (A14), IC2.4 (A14), OKI1.2, TI1.2
A15: D8.1 (K), E1.1, IC1.37 (A15), IC2.5 (A15), IC24.10
D0: E1.5, IC2.14 (D0), IC5.11 (D0), IC15.2 (D), IC15.14 (G), R1.2, R9.2
D1: E1.6, IC2.15 (D1), IC5.12 (D1), IC16.2 (D), IC16.14 (G), R2.2, R10.2
D2: E1.7, IC2.12 (D2), IC5.13 (D2), IC17.2 (D), IC17.14 (G), R3.2, R11.1
D3: E1.10, IC2.8 (D3), IC5.15 (D3), IC18.2 (D), IC18.14 (G), R4.2, R12.1
D4: E1.11, IC2.7 (D4), IC5.16 (D4), IC19.2 (D), IC19.14 (G), R5.2, R13.1
D5: E1.9, IC2.9 (D5), IC5.17 (D5), IC20.2 (D), IC20.14 (G), R6.2, R14.1
D6: E1.8, IC2.10 (D6), IC5.18 (D6), IC21.2 (D), IC21.14 (G), R7.2, R15.1
D7: E1.3, IC2.13 (D7), IC5.19 (D7), IC22.2 (D), IC22.14 (G), R8.2, R16.1
GND: C1.1, C2.1, C3.1, C4.1, C5.2, C6.2, C7.2, C8.2, C25.2, C26.2, C27.2, C28.2, C29.1, C30.1, C33.2, C34.2, C35.1, C37.2, C40.2, C41.2, C42.2, C43.2, C44.2, C45.2, C47.1, C48.2, C49.2, C50.2, C54.2, C55.2, C56.2, C57.2, C58.2, C59.1, C60.1, C61.2, C62.2, C63.2, C64.2, C66.2, C72.2, C73.1, C75.1, C76.1, C77.2, D11.1 (K), D13.2 (A), D16.1 (K), E1.32, E1.33, E1.40, EAR1.1, IC1.40 (GND), IC2.29 (GND), IC3.8 (GND), IC3.15 (STROBE), IC4.8 (GND), IC4.15 (STROBE), IC5.14 (Vss), IC6.16 (VSS), IC7.16 (VSS), IC8.16 (VSS), IC9.16 (VSS), IC10.16 (VSS), IC11.16 (VSS), IC12.16 (VSS), IC13.16 (VSS), IC14.5 (GROUND), IC15.1 (NC), IC15.16 (VSS), IC16.1 (NC), IC16.16 (VSS), IC17.1 (NC), IC17.16 (VSS), IC18.1 (NC), IC18.16 (VSS), IC19.1 (NC), IC19.16 (VSS), IC20.1 (NC), IC20.16 (VSS), IC21.1 (NC), IC21.16 (VSS), IC22.1 (NC), IC22.16 (VSS), IC23.7 (GND), IC24.7 (GND), IC25.8 (GND), IC25.15 (STROBE), IC26.8 (GND), IC26.15 (STROBE), J7.1, LS1.1, MIC1.1, OKI-L1.1, R37.2, R43.2, R46.2, R47.1, R50.2, R52.2, R53.2, R54.2, R56.1, R58.2, R63.1, REG1.2 (GND), TI-3.1, TR3.3 (E), TR4.3 (E), TV1.3 (GND)
NC: J7.3 (MP2)
unnamed: C31.1, R35.2
unnamed: C31.2, MIC1.2
unnamed: C32.1, R36.2
unnamed: C38.1, C39.2, R46.1
unnamed: C38.2, R45.2, X2.2
unnamed: C43.1, R60.1, R61.1
unnamed: C63.1, IC23.9, R71.1
unnamed: C64.1, IC23.5, R70.1
unnamed: C72.1, R44.2, X2.1
unnamed: C73.2, X1.1
unnamed: D1.2 (A), KB2.1, KB2.11 (Pin_1A)
unnamed: D2.2 (A), KB2.2, KB2.12 (Pin_2A)
unnamed: D3.2 (A), KB2.3, KB2.13 (Pin_3A)
unnamed: D4.2 (A), KB2.4, KB2.14 (Pin_4A)
unnamed: D5.2 (A), KB2.5, KB2.15 (Pin_5A)
unnamed: D6.2 (A), KB2.6, KB2.16 (Pin_6A)
unnamed: D7.2 (A), KB2.7, KB2.17 (Pin_7A)
unnamed: D8.2 (A), KB2.8, KB2.18 (Pin_8A)
unnamed: D9.1 (K), TR7.2 (B)
unnamed: C46.2, D11.2 (A), R55.1
unnamed: D12.1 (K), D16.2 (A), R55.2
unnamed: C32.2, C35.2, D9.2 (A), D13.1 (K), IC1.28 (MIC/TAPE), R35.1
unnamed: EAR1.2, R36.1, R37.1
unnamed: IC1.18 (D0), IC6.2 (DIN), IC6.14 (DOUT), R1.1
unnamed: IC1.21 (D1), IC7.2 (DIN), IC7.14 (DOUT), R2.1
unnamed: IC1.22 (D2), IC8.2 (DIN), IC8.14 (DOUT), R3.1
unnamed: IC1.25 (D3), IC9.2 (DIN), IC9.14 (DOUT), R4.1
unnamed: IC1.27 (D4), IC10.2 (DIN), IC10.14 (DOUT), R5.1
unnamed: IC1.29 (D5), IC11.2 (DIN), IC11.14 (DOUT), R6.1
unnamed: IC1.30 (D6), IC12.2 (DIN), IC12.14 (DOUT), R7.1
unnamed: IC1.31 (D7), IC13.2 (DIN), IC13.14 (DOUT), R8.1
unnamed: IC1.19 (KB0), KB1.1, KB1.11 (A1), R69.2
unnamed: IC1.20 (KB1), KB1.2, KB1.12 (2A), R68.2
unnamed: IC1.23 (KB2), KB1.3, KB1.13 (3A), R67.2
unnamed: IC1.24 (KB3), KB1.4, KB1.14 (4A), R66.2
unnamed: IC1.26 (KB4), KB1.5, KB1.15 (5A), R65.2
unnamed: IC1.39 (OSC), X1.2
unnamed: C30.2, IC1.13 (Vcc2), R34.2
unnamed: IC1.12 (_INT), R26.1
unnamed: IC1.34 (_ROMCS), R33.2
unnamed: IC2.6 (~CLK), R25.1, TR3.1 (C)
unnamed: IC3.4 (1Y), R22.2
unnamed: IC3.7 (2Y), R21.2
unnamed: IC3.9 (3Y), R20.2
unnamed: IC3.12 (4Y), R23.2
unnamed: IC3.1 (S), IC4.1 (S), R32.1
unnamed: IC4.4 (1Y), R18.2
unnamed: IC4.7 (2Y), R17.2
unnamed: IC4.12 (4Y), R19.2
unnamed: IC5.20 (CS), JROM1.1
unnamed: IC5.27 (OE1L), JROM1.4
unnamed: C52.2, IC14.4 (B-Y_INPUT), R76.1
unnamed: C76.2, IC14.3 (CHROMA_BIAS), R78.1
unnamed: C37.1, IC14.18 (CHROMA_LAG), R45.1
unnamed: C39.1, IC14.1 (CHROMA_LEAD)
unnamed: IC14.17 (CHROMA_OSC_OUTPUT), R43.1, R44.1
unnamed: C65.1, IC14.13 (CHROMA_SUB-CARRIER), R72.2
unnamed: C53.2, IC14.2 (R-Y_INPUT), R77.1
unnamed: IC14.12 (VIDEO_INPUT), R42.2
unnamed: IC23.10, IC24.8
unnamed: IC24.6, IC24.9
unnamed: IC23.8, IC25.1 (S), IC26.1 (S), R70.2
unnamed: IC26.11 (3A), OKI-H1.2, OKI-L1.2, TI1.1
unnamed: IC26.10 (3B), OKI1.1, TI-3.2, TI-4.2
unnamed: C77.1, R61.2, T1.1 (AA)
unnamed: T1.2 (AB), TR4.2 (B)
unnamed: R48.2, R49.2, R50.1, TR1.2 (B)
unnamed: C65.2, R51.2, TR1.1 (C), TR2.2 (B)
unnamed: R52.1, TR1.3 (E)
unnamed: C25.1, C40.1, C42.1, R49.1, R51.1, R64.1, R72.1, TR2.1 (C), TV1.1 (+5V)
unnamed: C67.1, R24.1, TR3.2 (B)
unnamed: C74.2, R58.1, R59.1, TR5.2 (B)
unnamed: R60.2, TR5.1 (C)
unnamed: LS1.2, TR7.3 (E)
unnamed: C70.1, R75.1, TR8.2 (B)
unnamed: C71.1, R77.2, TR8.1 (C)
unnamed: C68.1, R74.1, TR9.2 (B)
unnamed: C69.1, R76.2, TR9.1 (C)
U: C69.2, E1.44, IC1.15 (u), R56.2
V: C71.2, E1.43, IC1.16 (v), R63.2
VIDEO: E1.41, R53.1, TR2.3 (E), TV1.2 (1P)
Y: C68.2, C70.2, E1.42, IC1.17 (h), R47.2, R48.1
_BUSACK: E1.52, IC2.23 (~BUSACK)
_BUS_REQ: E1.45, IC2.25 (~BUSRQ), R30.1
_CK: C67.2, E1.34, IC1.32 (_CPU), R24.2, R73.1
_HALT: E1.14, IC2.18 (~HALT)
_INT: E1.12, IC2.16 (~INT), R26.2
_IO_REQ: E1.16, IC2.20 (~IORQ), R27.2
_IO_RQULA: E1.39, IC1.33 (_IOREQ), R27.1, TR6.3 (E)
_M1: E1.23, IC2.27 (~M1)
_M_REQ: E1.15, IC1.38 (_MREQ), IC2.19 (~MREQ), IC23.1, IC23.2, JROM1.2
_NMI: E1.13, IC2.17 (~NMI), R28.1
_RD: E1.17, IC1.3 (_R0), IC2.21 (~RD), IC5.22 (OE0L), IC24.4
_RESET: C27.1, E1.46, IC2.26 (~RESET), R31.2
_RFSH: C54.1, E1.24, IC2.28 (~RFSH), R57.2
_ROMCS: E1.51, JROM1.3, R33.1
_WAIT: E1.20, IC2.24 (~WAIT), R29.1
_WR: E1.18, IC1.2 (_WR), IC2.22 (~WR), IC23.12, IC23.13

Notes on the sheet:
Optional 32K RAM For TI memory devices link TI and either TI-4 OR TI-3 For OKI memory devices link OKI and either OKI-H or OKI-L If fitting 64K devices, use either OKI or TI, not both.
NEC HITACHI Pin20 CE CS Pin27 CS CE
Underside Comp Side A B A14 1 A15 A13 2 A13 +5V 3 D7 +9V 4 NC SLOT 5 SLOT 0V 6 D0 0V 7 D1 -CK 8 D2 A0 9 D6 A1 10 D5 A2 11 D3 A3 12 D4 -IO_RQULA 13 -INT 0V 14 -NMI VIDEO 15 -HALT -Y 16 -M_REQ V 17 -IO_REQ U 18 -RD -BUS_REQ 19 -WR -RESET 20 -5V A7 21 -WAIT A6 22 +12V A5 23 -12V (12VAC) A4 24 -M1 -ROM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
1-2 & 3-4 = NEC 1-3 & 2-4 = Hitachi

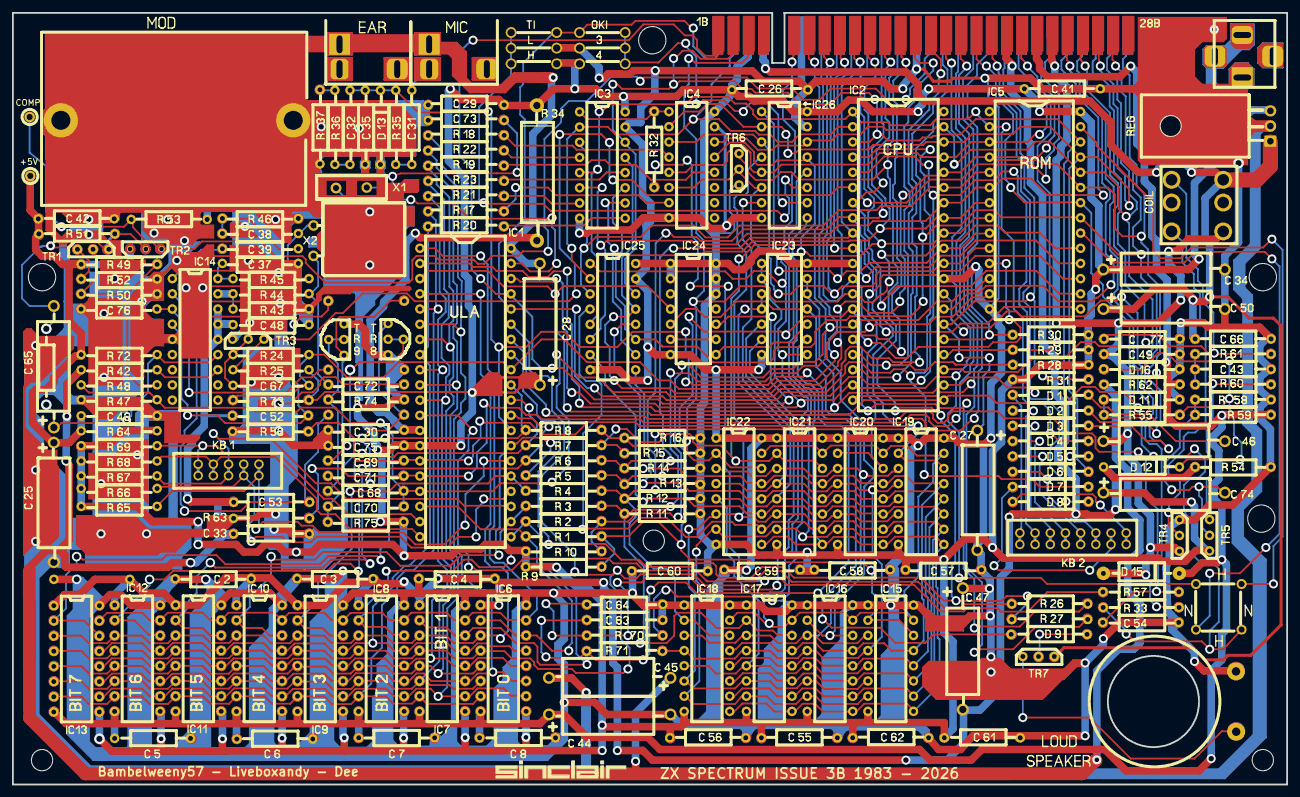
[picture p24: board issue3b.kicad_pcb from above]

Board: 2 copper layers, 213.1 x 129.0 mm, 201 parts (0 on the bottom side), 150 nets.

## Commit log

2026-08-30 changed to kicad 10 and added bljall-alt 3d models.
    [AUDIO_JACK_3PIN.obj, AUDIO_JACK_3PIN.step, COIL_L1.obj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]
2026-08-30 name change
    [issue3b.kicad_pcb]
2026-08-31 Major updates thanks to Liveboxandy and Dee. Some rework from Bambelweeny57.
    [13.34x13.34 Bobin.STEP, 22-02-3053.stp, 22-02-3083.stp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]
2026-08-31 work on footprints
    [issue3b - Copy.kicad_pcb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]
2026-09-01 New speaker from Dee.
    [COIL_L1.step, ZX Spectrum 48k Speaker.step, ZX Spectrum Speaker 40ohm.step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]
2026-09-03 more 3d models added from Dee
    [FERRANTI_ULA_6C001E-7.step, ROM HITACHI HN613128P.step, Z80 - NEC 8308P8.step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]
2026-09-07 extra 3d parts from Dee inc heat sink.
    [Axial Capacitor.step, DO-35_P12.70_BA157.step, Jumper.step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]
2026-09-12 iBOM, final bits on 3D models from Dee.
    [Axial Capacitor.step, issue3b - Copy.kicad_pcb, issue3b.dsn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]
2026-09-13 extra 3d models from Dee
    [ITT_4116.step, MOT_SN74532N.step, MOT_SN74LS00N.step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]
2026-09-13 moved kb1 to lower row.
    [issue3b.kicad_pcb]
2026-09-19 new lower ram, sss cpu and nec rom from dee
    [ROM NEC D2318C.step, STC_4116.step, Z80 - SGS.step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]
2026-09-19 added dee's caps
    [CAP_AXIAL_THT_L5.1-D3.1-P12.70.step, issue3b.kicad_pcb]
2026-09-27 replaced electrolytic and ceramic caps with updated versions and replaced signal diodes with Dee's.
    [CAP-TH_BD6.3-L12.0-P20.32-D0.6.step, CAP_AXIAL_THT_L5.1-D3.1-P12.70.step, DO-35_P12.70-D0.53.step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]
2026-09-27 Added Dee's ZX450.
    [ZTX_450.step, issue3b.kicad_pcb]
2026-09-27 Added Dee's BC184
    [BC184.step, issue3b.kicad_pcb]
